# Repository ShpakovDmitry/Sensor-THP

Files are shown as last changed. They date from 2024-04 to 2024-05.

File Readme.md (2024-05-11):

<p align="right">
  
</p>

### Status
<p align="left">
  
  
  </br>
  
  
</p>

### Description
Wireless 2.4GHz temperature, humidity and atmospheric pressure sensor.

### Rendered board view

<p align="middle">
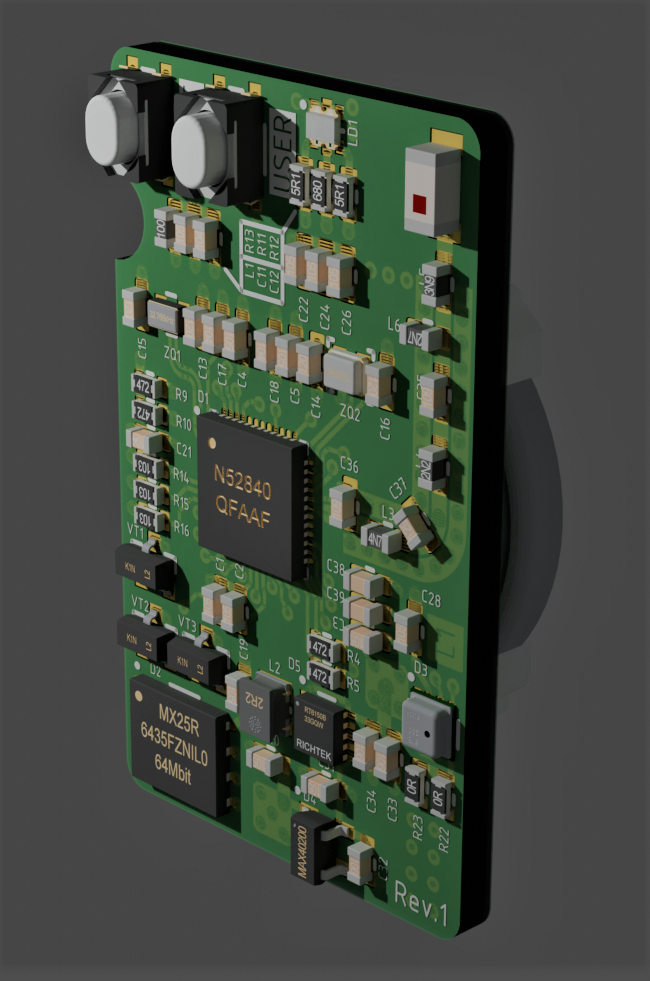
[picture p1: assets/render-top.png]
  
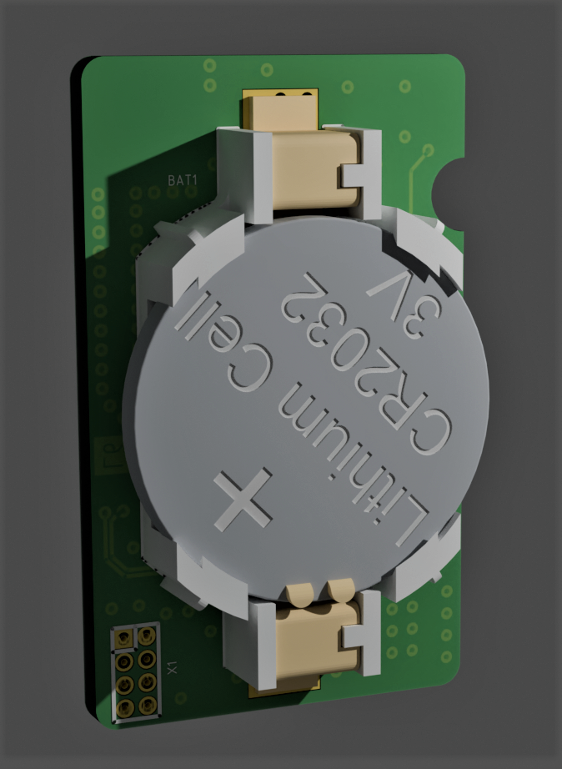
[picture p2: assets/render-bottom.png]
   
</p>

### Hardware
For hardware related information, like where is programming interface and its
pinout, board layout, fabrication files, documentation and schematics, goto
hardware directory.

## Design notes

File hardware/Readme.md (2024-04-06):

### Board view
With components 
<p align="middle">
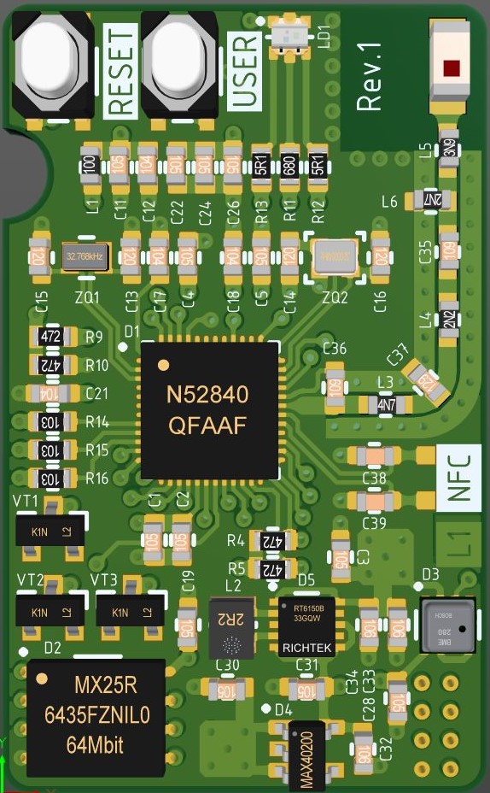
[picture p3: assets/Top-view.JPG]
  
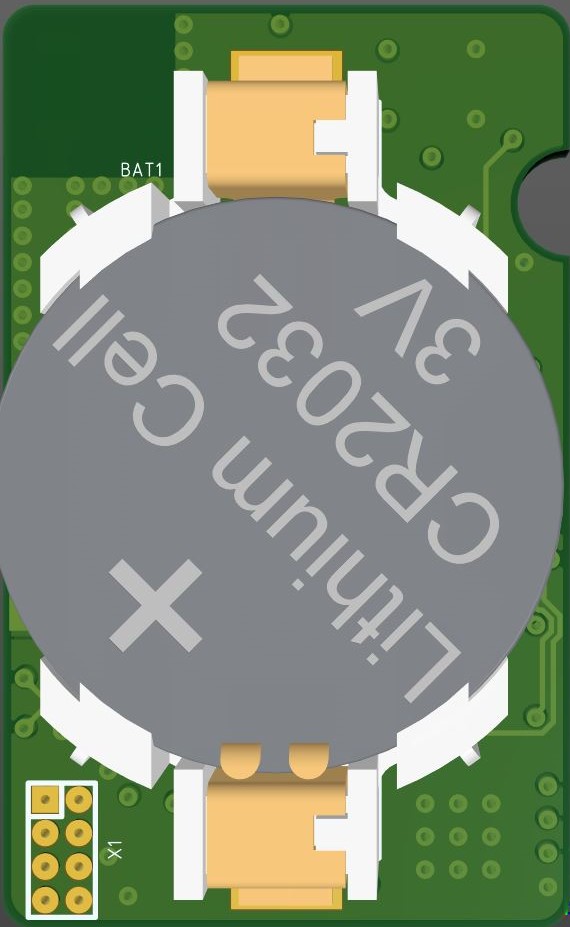
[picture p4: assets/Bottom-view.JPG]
  
</p> 
Without components
<p align="middle">
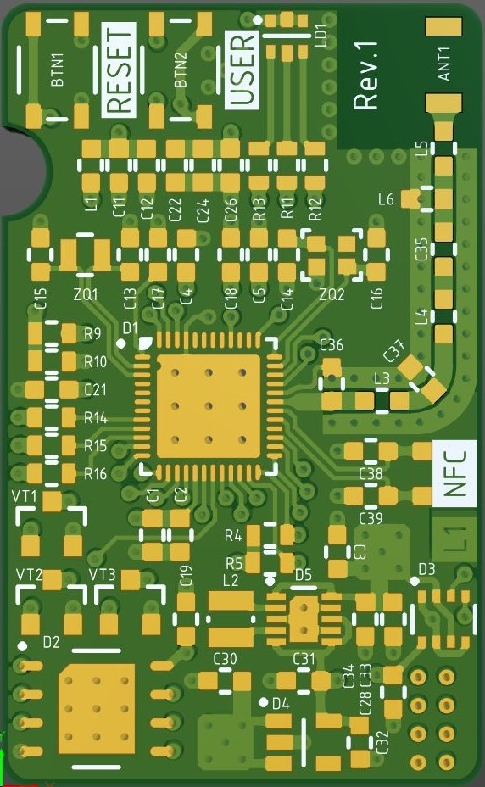
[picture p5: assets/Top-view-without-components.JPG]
  
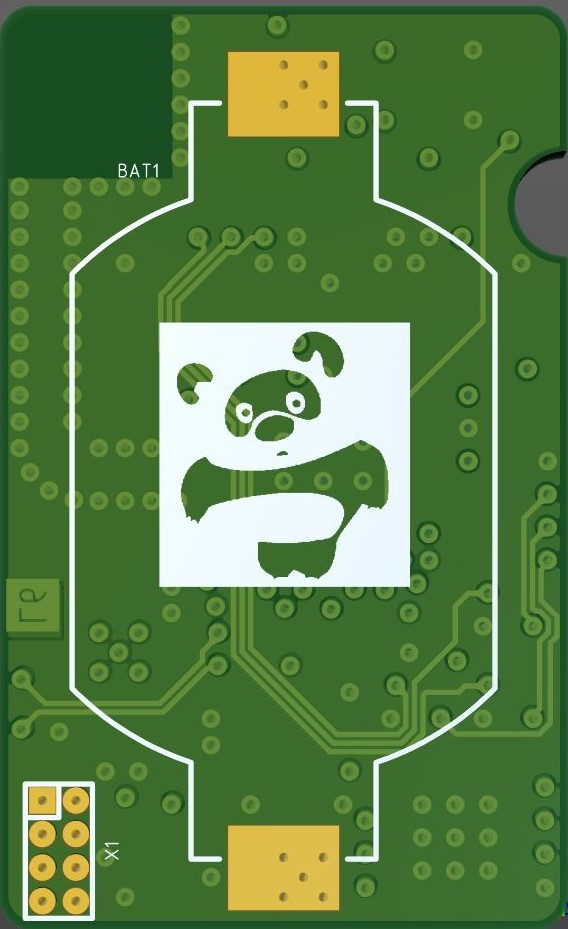
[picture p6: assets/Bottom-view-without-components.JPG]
  
</p> 

### Programming interface
<p align="middle">
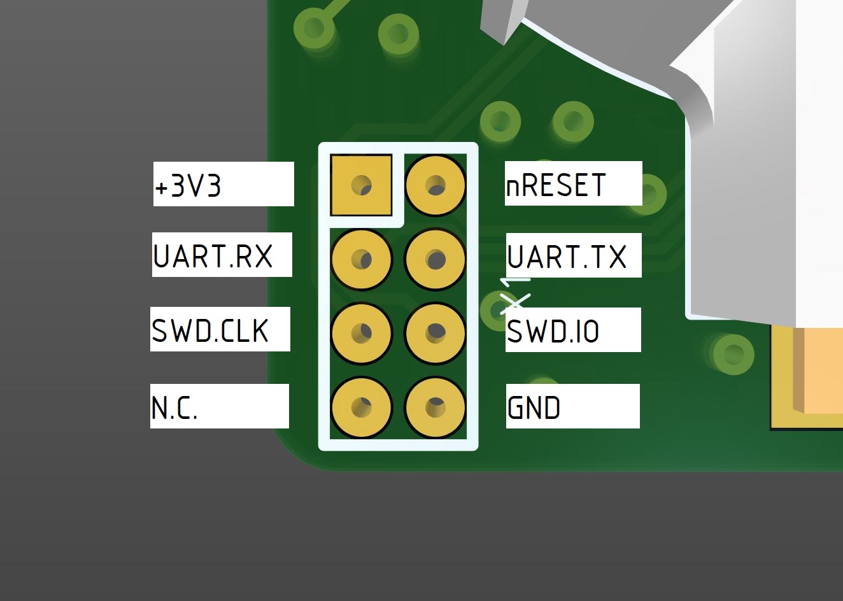
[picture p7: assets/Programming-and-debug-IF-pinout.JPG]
  
</p>

### Layer stackup
Board is 6 layer stackup with the following layer purpose:
<p align="middle">
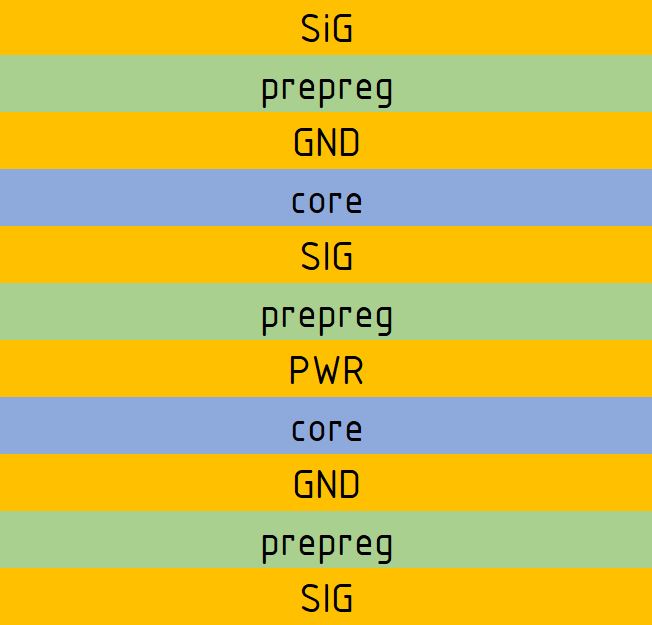
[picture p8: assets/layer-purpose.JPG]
  
</p> 

Detailed information about PCB layer stackup could be find
here

### Layer view
<p align="middle">
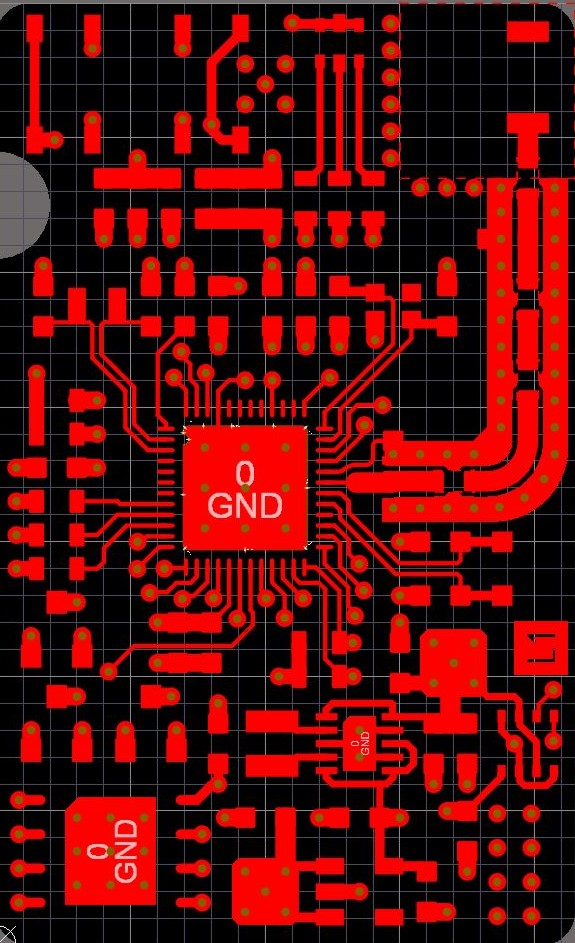
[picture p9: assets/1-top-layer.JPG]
  
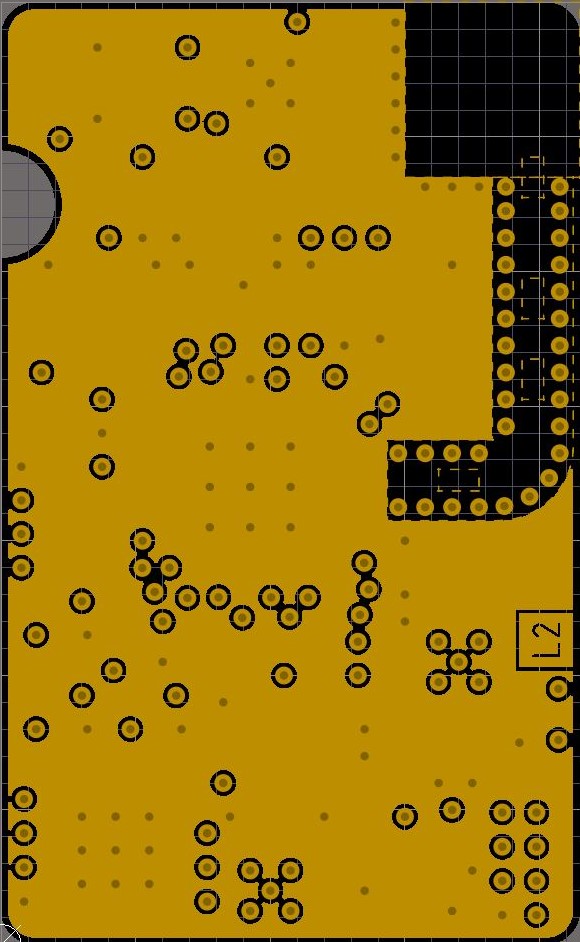
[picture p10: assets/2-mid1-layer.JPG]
  
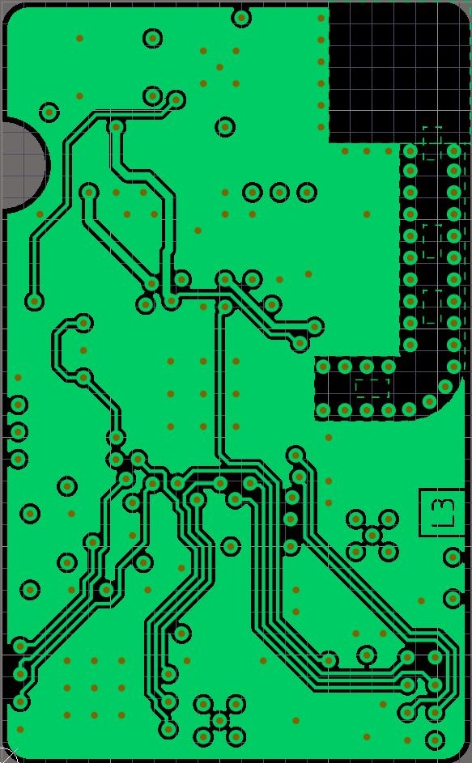
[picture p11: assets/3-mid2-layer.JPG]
  
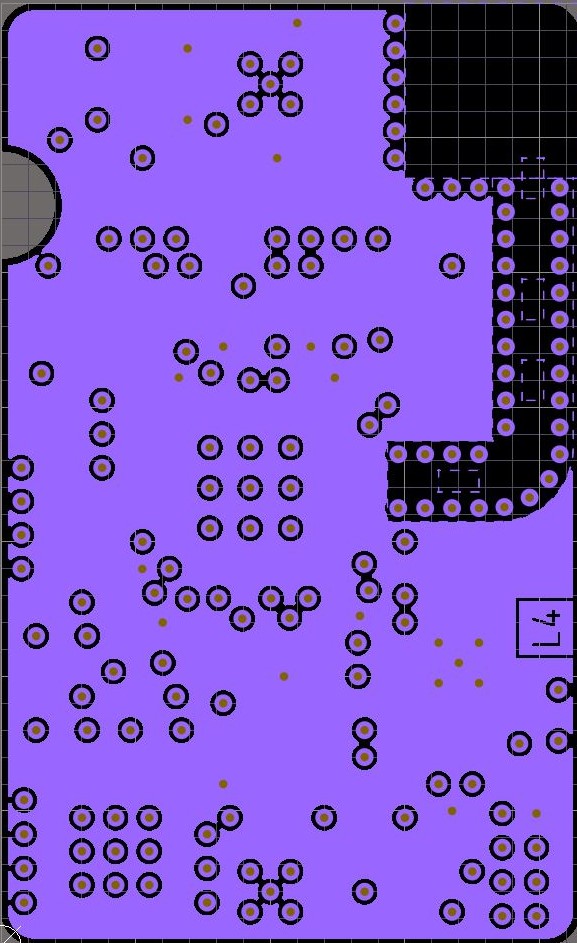
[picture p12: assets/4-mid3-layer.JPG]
  
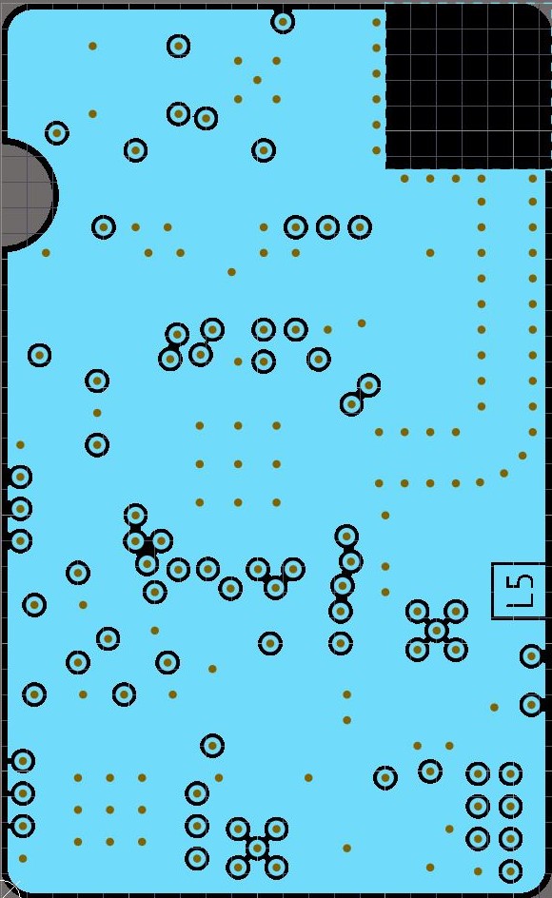
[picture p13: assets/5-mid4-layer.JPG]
  
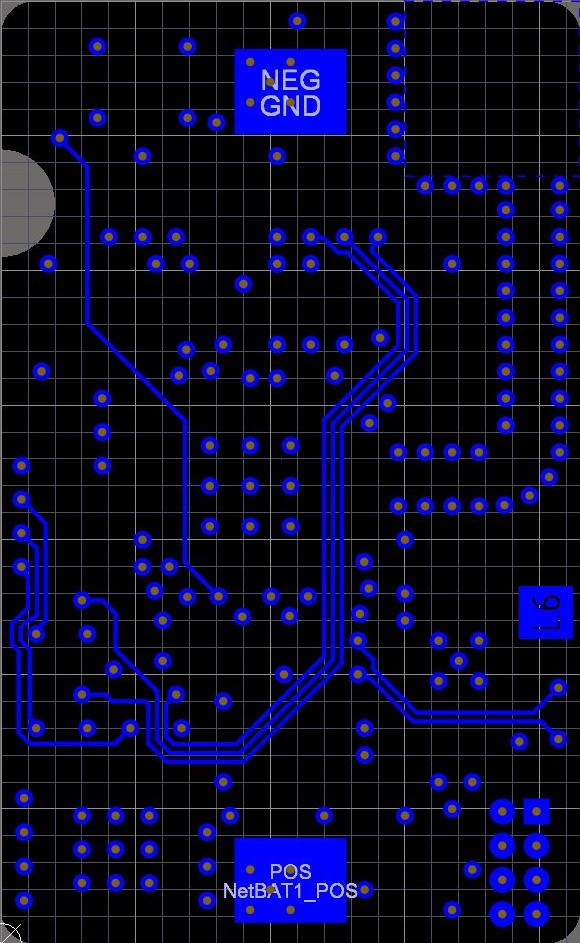
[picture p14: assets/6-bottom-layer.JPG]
  
</p>

### Schematics
Up to date version of schematics is here

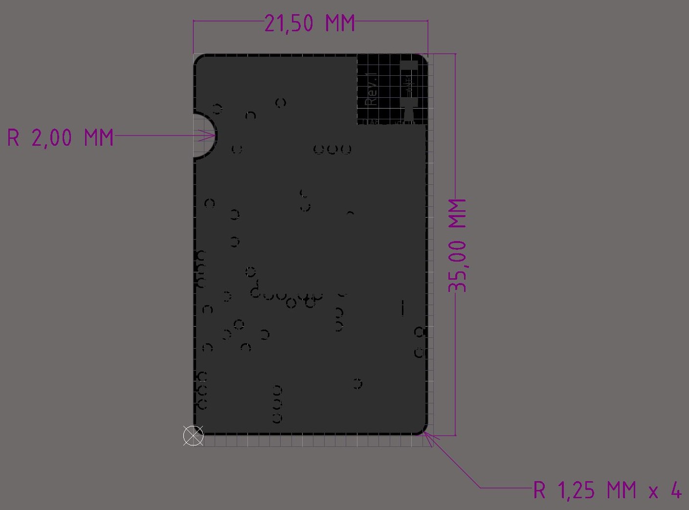
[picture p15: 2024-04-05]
assets/board-dimensions.JPG

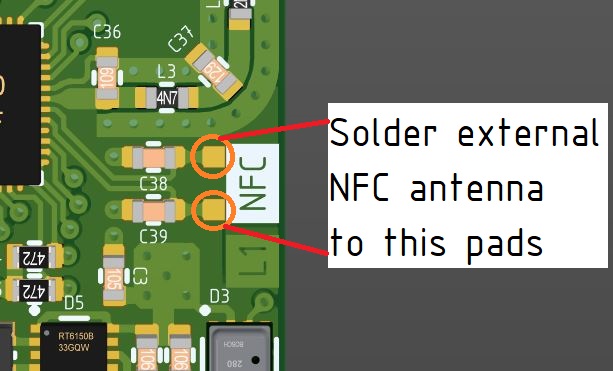
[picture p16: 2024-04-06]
assets/NFC-antenna-connection-IF.JPG

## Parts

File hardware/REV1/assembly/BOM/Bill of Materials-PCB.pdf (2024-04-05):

Designator | Quantity Assembly | | Package | Comment | Description | Manufacturer | Manufacturer Part Number | HelpURL | | | Supplier | Supplier Part Number | Price @ 1 pcsPrice @ 10 pcsPrice @ 100 pcsPrice @ 1000 pcs Last Update | | | | | Total cost for 1 PCB | Total cost for 10 PCB | Total cost for 100 PCB | Total cost for 1000 PCB
ANT1 | 1 | | | 2450AT18A0100001E | 2.4GHz Chip RF Antenna 2.4GHz ~ 2.5GHz 0.5dBi Solder Surface Mount | Johanson Technology Inc. | 2450AT18A0100001E | | -40°C | +125°C | DigiKey | 712-2450AT18A0100001ECT-ND | 0.55000€ | 0.48500€ | 0.37170€ | 0.23502€ | 2024.03.06 | 0.55 € | 4.85 € | 37.17 € | 235.02 €
BAT1 | 1 | | | BU2032SM-BT-GTR | Battery Holder (Open) Coin, 20.0mm 1 Cell SMD (SMT) Tab | MPD (Memory Protection Devices) | BU2032SM-BT-GTR | | -40°C | +280°C | DigiKey | BU2032SM-BT-GCT-ND | 1.57000€ | 1.32300€ | 1.09600€ | 0.94604€ | 2024.02.15 | 1.57 € | 13.23 € | 109.60 € | 946.04 €
BTN1, BTN2 | 2 | | | PTS810 SJK 250 SMTR LFS | Tactile Switch SPST-NO Top Actuated Surface Mount | C&K | PTS810 SJK 250 SMTR LFS | | -40°C | +85°C | DigiKey | CKN10503CT-ND | 0.31000€ | 0.29700€ | 0.24280€ | 0.18445€ | 2024.02.09 | 0.62 € | 5.94 € | 48.56 € | 368.90 €
C1, C2, C3, C4, C5, C11, C19, C22, C24, C26, C28, C30, C31 | 13 | | 0603 | 1u | 1 µF ±10% 6.3V Ceramic Capacitor X5R 0603 (1608 Metric) | YAGEO | CC0603KRX5R5BB105 | | -55°C | +85°C | DigiKey | 311-1447-1-ND | 0.09000€ | 0.06100€ | 0.02890€ | 0.01765€ | 2024.02.06 | 0.79 € | 3.76 € | 22.95 € | 229.45 €
C12, C17, C18, C21 | 4 | | 0603 | 0.1u | 0.1 µF ±10% 10V Ceramic Capacitor X7R 0603 (1608 Metric) | YAGEO | CC0603KRX7R6BB104 | | -55°C | +125°C | DigiKey | 311-4055-1-ND | 0.09000€ | 0.06100€ | 0.02870€ | 0.01753€ | 2024.02.07 | 0.36 € | 2.44 € | 11.48 € | 70.12 €
C13, C14, C15, C16 | 4 | | 0603 | 12p | 12 pF ±5% 50V Ceramic Capacitor C0G, NP0 0603 (1608 Metric) | YAGEO | CC0603JPNPO9BN120 | | -55°C | +125°C | DigiKey | 13-CC0603JPNPO9BN120CT-ND | 0.09000€ | 0.04500€ | 0.01980€ | 0.01170€ | 2024.02.07 | 0.36 € | 1.80 € | 7.92 € | 46.80 €
C32, C33, C34 | 3 | | 0603 | 10u | 10 µF ±20% 6.3V Ceramic Capacitor X5R 0603 (1608 Metric) | YAGEO | CC0603MRX5R5BB106 | | -55°C | +85°C | DigiKey | 311-1448-1-ND | 0.20000€ | 0.13500€ | 0.07660€ | 0.04981€ | 2024.02.27 | 0.60 € | 4.05 € | 22.98 € | 149.43 €
C35, C36 | 2 | | 0603 | 1.0p | 1 pF ±0.1pF 250V Ceramic Capacitor C0G, NP0 0603 (1608 Metric) | Johanson Technology Inc. | QSCP251Q1R0B1GV001T | | -55°C | +125°C | DigiKey | 712-QSCP251Q1R0B1GV001TCT-ND | 0.20000€ | 0.13500€ | 0.07590€ | 0.04936€ | 2024.03.06 | 0.40 € | 2.70 € | 15.18 € | 98.72 €
C37 | 1 | | 0603 | 1.2p | 1.2 pF ±0.1pF 250V Ceramic Capacitor C0G, NP0 0603 (1608 Metric) | Johanson Technology Inc. | QSCP251Q1R2B1GV001T | | -55°C | +125°C | DigiKey | 712-QSCP251Q1R2B1GV001TCT-ND | 0.20000€ | 0.13400€ | 0.07590€ | 0.04936€ | 2024.03.06 | 0.20 € | 1.34 € | 7.59 € | 49.36 €
C38, C39 | 2 | DNP | 0603 | | | | | | | | | | | | | | | 0.00 € | 0.00 € | 0.00 € | 0.00 €
D1 | 1 | | QFN48 6x6mm 0.4mm pitch | nRF52840-QFAA-F | SoC 32bit ARM Cortex-M4F 1M Flash 256K RAM Single Core 64MHz 1.7V to 5.5V 2.4GHz Bluetooth 5.0 Surface Mount 48-Pin QFN | Nordic Semiconductor ASA | nRF52840-QFAA-F | | -40°C | +85°C | DigiKey | 4823-NRF52840-QFAA-F-RCT-ND | 5.98000€ | 5.48300€ | 4.48650€ | 3.36485€ | 2024.02.05 | 5.98 € | 54.83 € | 448.65 € | 3 364.85 €
D2 | 1 | | 8-WSON (6x5) 1.27mm pitch | MX25R6435FZNIL0 64MiB | FLASH - NOR Memory IC 64Mbit SPI - Quad I/O 80 MHz 8-WSON (6x5) | Macronix | MX25R6435FZNIL0 | | -40°C | +85°C | DigiKey | 1092-1201-ND | 1.72000€ | 1.56700€ | 1.35513€ | 1.33081€ | 2024.02.08 | 1.72 € | 15.67 € | 135.51 € | 1 330.81 €
D3 | 1 | | 8-LGA (2.5x2.5) | BME280 | Humidity, Pressure, Temperature 0 ~ 100% RH I2C, SPI ±3% 1 s Surface Mount | Bosch Sensortec | BME280 | | -40°C | +85°C | DigiKey | 828-1063-1-ND | 5.87000€ | 4.40400€ | 3.62050€ | 2.83773€ | 2024.02.13 | 5.87 € | 44.04 € | 362.05 € | 2 837.73 €
D4 | 1 | | SOT23-5 | MAX40200AUK+T | OR Controller Source Selector Switch P-Channel 1:1 SOT-23-5 | Analog Devices Inc./Maxim Integrated | MAX40200AUK+T | | -40°C | +125°C | DigiKey | MAX40200AUK+TCT-ND | 0.93000€ | 0.76500€ | 0.59560€ | 0.41122€ | 2024.02.27 | 0.93 € | 7.65 € | 59.56 € | 411.22 €
D5 | 1 | | 10-WDFN (2.5x2.5) | RT6150B-33GQW | Buck-Boost Switching Regulator IC Positive Fixed 3.3V 1 Output 800mA 10-WFDFN Exposed Pad | Richtek USA Inc. | RT6150B-33GQW | | -40°C | +85°C | DigiKey | RT6150B-33GQWCT-ND | 1.80000€ | 1.61400€ | 1.29720€ | 1.06576€ | 2024.02.27 | 1.80 € | 16.14 € | 129.72 € | 1 065.76 €
L1 | 1 | | 0603 | 10uH | 10 µH Shielded Multilayer Inductor 250 mA 1.05Ohm 0603 (1608 Metric) | TDK Corporation | MLZ1608M100WTD25 | | -55°C | +125°C | DigiKey | 445-175588-1-ND | 0.16000€ | 0.13600€ | 0.09630€ | 0.06609€ | 2024.02.08 | 0.16 € | 1.36 € | 9.63 € | 66.09 €
L2 | 1 | | 2520 | 2.2uH | 2.2 µH Shielded Drum Core, Wirewound Inductor 1.87 A 96mOhm Max Nonstandard | TDK Corporation | VLS252012CX-2R2M-1 | | -40°C | +105°C | DigiKey | 445-172983-1-ND | 0.35000€ | 0.29900€ | 0.22220€ | 0.15979€ | 2024.02.27 | 0.35 € | 2.99 € | 22.22 € | 159.79 €
L3 | 1 | | 0603 | 4.7nH | 4.7 nH Unshielded Multilayer Inductor 300 mA 300mOhm Max 0603 (1608 Metric) | Johanson Technology Inc. | LRC0603CS4N7GV001T | | -55°C | +100°C | DigiKey | 712-LRC0603CS4N7GV001TCT-ND | 0.09000€ | 0.04300€ | 0.03060€ | 0.02098€ | 2024.03.07 | 0.09 € | 0.43 € | 3.06 € | 20.98 €
L4 | 1 | | 0603 | 2.2nH | 2.2 nH Unshielded Multilayer Inductor 300 mA 150mOhm Max 0603 (1608 Metric) | Johanson Technology Inc. | LRC0603CS2N2GV001T | | -55°C | +100°C | DigiKey | 712-LRC0603CS2N2GV001TCT-ND | 0.09000€ | 0.04300€ | 0.03060€ | 0.02098€ | 2024.03.07 | 0.09 € | 0.43 € | 3.06 € | 20.98 €
L5 | 1 | | 0603 | 3.9nH | 3.9 nH Unshielded Multilayer Inductor 300 mA 250mOhm Max 0603 (1608 Metric) | Johanson Technology Inc. | LRC0603CS3N9GV001T | | -55°C | +100°C | DigiKey | 712-LRC0603CS3N9GV001TCT-ND | 0.09000€ | 0.04300€ | 0.03060€ | 0.02098€ | 2024.03.07 | 0.09 € | 0.43 € | 3.06 € | 20.98 €
L6 | 1 | | 0603 | 2.7nH | 2.7 nH Unshielded Multilayer Inductor 300 mA 200mOhm Max 0603 (1608 Metric) | Johanson Technology Inc. | LRC0603CS2N7GV001T | | -55°C | +100°C | DigiKey | 712-LRC0603CS2N7GV001TCT-ND | 0.09000€ | 0.04300€ | 0.03060€ | 0.02098€ | 2024.03.07 | 0.09 € | 0.43 € | 3.06 € | 20.98 €
LD1 | 1 | | 0606 | EAST1616RGBA8 | Red, Green, Blue (RGB) 624nm Red, 525nm Green, 468nm Blue LED Indication - Discrete 2.05V Red, 3.2V Green, 3.2V Blue 0606 (1616 Metric) | Everlight Electronics Co Ltd | EAST1616RGBA8 | | -40°C | +85°C | DigiKey | 1080-EAST1616RGBA8CT-ND | 0.48000€ | 0.29500€ | 0.16980€ | 0.13293€ | 2024.02.14 | 0.48 € | 2.95 € | 16.98 € | 132.93 €
R4, R5, R9, R10 | 4 | | 0603 | 4k7 | 4.7 kOhms ±5% 0.1W, 1/10W Chip Resistor 0603 (1608 Metric) Moisture Resistant Thick Film | YAGEO | RC0603JR-074K7L | | -55°C | +155°C | DigiKey | 311-4.7KGRCT-ND | 0.09000€ | 0.01400€ | 0.00690€ | 0.00399€ | 2024.02.09 | 0.36 € | 0.56 € | 2.76 € | 15.96 €
R11 | 1 | | 0603 | 68R | 68 Ohms ±1% 0.1W, 1/10W Chip Resistor 0603 (1608 Metric) Moisture Resistant Thick Film | YAGEO | RC0603FR-0768RL | | -55°C | +155°C | DigiKey | 311-68.0HRCT-ND | 0.09000€ | 0.01700€ | 0.00850€ | 0.00486€ | 2024.02.14 | 0.09 € | 0.17 € | 0.85 € | 4.86 €
R12, R13 | 2 | | 0603 | 5R1 | 5.1 Ohms ±5% 0.1W, 1/10W Chip Resistor 0603 (1608 Metric) Moisture Resistant Thick Film | YAGEO | RC0603JR-075R1L | | -55°C | +155°C | DigiKey | 311-5.1GRCT-ND | 0.09000€ | 0.02400€ | 0.01250€ | 0.00743€ | 2024.02.14 | 0.18 € | 0.48 € | 2.50 € | 14.86 €
R14, R15, R16 | 3 | | 0603 | 10k | 10 kOhms ±1% 0.1W, 1/10W Chip Resistor 0603 (1608 Metric) Moisture Resistant Thick Film | YAGEO | RC0603FR-0710KL | | -55°C | +155°C | DigiKey | 311-10.0KHRCT-ND | 0.09000€ | 0.01700€ | 0.00850€ | 0.00486€ | 2024.02.14 | 0.27 € | 0.51 € | 2.55 € | 14.58 €
VT1, VT2, VT3 | 3 | | SOT-23-3 | MMBT3904-7-F | Bipolar (BJT) Transistor NPN 40 V 200 mA 300MHz 300 mW Surface Mount SOT-23-3 | Diodes Incorporated | MMBT3904-7-F | | -55°C | +150°C | DigiKey | MMBT3904-FDICT-ND | 0.11000€ | 0.07900€ | 0.04270€ | 0.02326€ | 2024.02.14 | 0.33 € | 2.37 € | 12.81 € | 69.78 €
ZQ1 | 1 | | 2-smd | 32.768kHz | 32.768 kHz ±20ppm Crystal 9pF 90 kOhms 2-SMD, No Lead | Jauch Quartz Q 0,032768-JTX210-9-20-T1-80K-LF | | | -40°C | +85°C | DigiKey | 1908-1304-1-ND | 0.60000€ | 0.53100€ | 0.43850€ | 0.34618€ | 2024.02.08 | 0.60 € | 5.31 € | 43.85 € | 346.18 €
ZQ2 | 1 | | 4-smd | 32.0000MHz | 32 MHz ±20ppm Crystal 8pF 100 Ohms 4-SMD, No Lead | Murata Electronics | XRCGB32M000F2P01R0 | | -30°C | +85°C | DigiKey | 490-18340-1-ND | 0.20000€ | 0.16700€ | 0.13390€ | 0.11791€ | 2024.02.07 | 0.20 € | 1.67 € | 13.39 € | 117.91 €
Total: | 25.13 € | 198.53 € | 1 558.70 € | 12 231.07 €

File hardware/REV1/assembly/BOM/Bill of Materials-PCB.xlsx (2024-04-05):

Designator | Quantity | Assembly | Package | Comment | Description | Manufacturer | Manufacturer Part Number | HelpURL | Min Operating Temperature | Max Operating Temperature | Supplier | Supplier Part Number | Price @ 1 pcs | Price @ 10 pcs | Price @ 100 pcs | Price @ 1000 pcs | Last Update |  | Total cost for 1 PCB | Total cost for 10 PCB | Total cost for 100 PCB | Total cost for 1000 PCB
ANT1 | 1 |  |  | 2450AT18A0100001E | 2.4GHz Chip RF Antenna 2.4GHz ~ 2.5GHz 0.5dBi Solder Surface Mount | Johanson Technology Inc. | 2450AT18A0100001E | https://www.digikey.com/en/products/detail/johanson-technology-inc/2450AT18A0100001E/1560676 | -40°C | +125°C | DigiKey | 712-2450AT18A0100001ECT-ND | 0.55000€ | 0.48500€ | 0.37170€ | 0.23502€ | 2024.03.06 |  | 0.55 € | 4.85 € | 37.17 € | 235.02 €
BAT1 | 1 |  |  | BU2032SM-BT-GTR | Battery Holder (Open) Coin, 20.0mm 1 Cell SMD (SMT) Tab | MPD (Memory Protection Devices) | BU2032SM-BT-GTR | https://www.digikey.com/en/products/detail/mpd-memory-protection-devices/BU2032SM-BT-GTR/2439521 | -40°C | +280°C | DigiKey | BU2032SM-BT-GCT-ND | 1.57000€ | 1.32300€ | 1.09600€ | 0.94604€ | 2024.02.15 |  | 1.57 € | 13.23 € | 109.60 € | 946.04 €
BTN1, BTN2 | 2 |  |  | PTS810 SJK 250 SMTR LFS | Tactile Switch SPST-NO Top Actuated Surface Mount | C&K | PTS810 SJK 250 SMTR LFS | https://www.digikey.com/en/products/detail/c-k/PTS810-SJK-250-SMTR-LFS/4176611 | -40°C | +85°C | DigiKey | CKN10503CT-ND | 0.31000€ | 0.29700€ | 0.24280€ | 0.18445€ | 2024.02.09 |  | 0.62 € | 5.94 € | 48.56 € | 368.90 €
C1, C2, C3, C4, C5, C11, C19, C22, C24, C26, C28, C30, C31 | 13 |  | 0603 | 1u | 1 µF ±10% 6.3V Ceramic Capacitor X5R 0603 (1608 Metric) | YAGEO | CC0603KRX5R5BB105 | https://www.digikey.com/en/products/detail/yageo/CC0603KRX5R5BB105/2833612 | -55°C | +85°C | DigiKey | 311-1447-1-ND | 0.09000€ | 0.06100€ | 0.02890€ | 0.01765€ | 2024.02.06 |  | 0.79 € | 3.76 € | 22.95 € | 229.45 €
C12, C17, C18, C21 | 4 |  | 0603 | 0.1u | 0.1 µF ±10% 10V Ceramic Capacitor X7R 0603 (1608 Metric) | YAGEO | CC0603KRX7R6BB104 | https://www.digikey.com/en/products/detail/yageo/CC0603KRX7R6BB104/5883741 | -55°C | +125°C | DigiKey | 311-4055-1-ND | 0.09000€ | 0.06100€ | 0.02870€ | 0.01753€ | 2024.02.07 |  | 0.36 € | 2.44 € | 11.48 € | 70.12 €
C13, C14, C15, C16 | 4 |  | 0603 | 12p | 12 pF ±5% 50V Ceramic Capacitor C0G, NP0 0603 (1608 Metric) | YAGEO | CC0603JPNPO9BN120 | https://www.digikey.com/en/products/detail/yageo/CC0603JPNPO9BN120/11490158 | -55°C | +125°C | DigiKey | 13-CC0603JPNPO9BN120CT-ND | 0.09000€ | 0.04500€ | 0.01980€ | 0.01170€ | 2024.02.07 |  | 0.36 € | 1.80 € | 7.92 € | 46.80 €
C32, C33, C34 | 3 |  | 0603 | 10u | 10 µF ±20% 6.3V Ceramic Capacitor X5R 0603 (1608 Metric) | YAGEO | CC0603MRX5R5BB106 | https://www.digikey.com/en/products/detail/yageo/CC0603MRX5R5BB106/2833613 | -55°C | +85°C | DigiKey | 311-1448-1-ND | 0.20000€ | 0.13500€ | 0.07660€ | 0.04981€ | 2024.02.27 |  | 0.60 € | 4.05 € | 22.98 € | 149.43 €
C35, C36 | 2 |  | 0603 | 1.0p | 1 pF ±0.1pF 250V Ceramic Capacitor C0G, NP0 0603 (1608 Metric) | Johanson Technology Inc. | QSCP251Q1R0B1GV001T | https://www.digikey.com/en/products/detail/johanson-technology-inc/QSCP251Q1R0B1GV001T/1561575 | -55°C | +125°C | DigiKey | 712-QSCP251Q1R0B1GV001TCT-ND | 0.20000€ | 0.13500€ | 0.07590€ | 0.04936€ | 2024.03.06 |  | 0.40 € | 2.70 € | 15.18 € | 98.72 €
C37 | 1 |  | 0603 | 1.2p | 1.2 pF ±0.1pF 250V Ceramic Capacitor C0G, NP0 0603 (1608 Metric) | Johanson Technology Inc. | QSCP251Q1R2B1GV001T | https://www.digikey.com/en/products/detail/johanson-technology-inc/QSCP251Q1R2B1GV001T/1561577 | -55°C | +125°C | DigiKey | 712-QSCP251Q1R2B1GV001TCT-ND | 0.20000€ | 0.13400€ | 0.07590€ | 0.04936€ | 2024.03.06 |  | 0.20 € | 1.34 € | 7.59 € | 49.36 €
C38, C39 | 2 | DNP | 0603 |  |  |  |  |  |  |  |  |  |  |  |  |  |  |  | 0.00 € | 0.00 € | 0.00 € | 0.00 €
D1 | 1 |  | QFN48 6x6mm 0.4mm pitch | nRF52840-QFAA-F | SoC 32bit ARM Cortex-M4F 1M Flash 256K RAM Single Core 64MHz 1.7V to 5.5V 2.4GHz Bluetooth 5.0 Surface Mount 48-Pin QFN | Nordic Semiconductor ASA | nRF52840-QFAA-F | https://infocenter.nordicsemi.com/pdf/nRF52840_PS_v1.7.pdf | -40°C | +85°C | DigiKey | 4823-NRF52840-QFAA-F-RCT-ND | 5.98000€ | 5.48300€ | 4.48650€ | 3.36485€ | 2024.02.05 |  | 5.98 € | 54.83 € | 448.65 € | 3364.85 €
D2 | 1 |  | 8-WSON (6x5) 1.27mm pitch | MX25R6435FZNIL0 64MiB | FLASH - NOR Memory IC 64Mbit SPI - Quad I/O 80 MHz 8-WSON (6x5) | Macronix | MX25R6435FZNIL0 | https://www.digikey.com/en/products/detail/macronix/MX25R6435FZNIL0/6558605 | -40°C | +85°C | DigiKey | 1092-1201-ND | 1.72000€ | 1.56700€ | 1.35513€ | 1.33081€ | 2024.02.08 |  | 1.72 € | 15.67 € | 135.51 € | 1330.81 €
D3 | 1 |  | 8-LGA (2.5x2.5) | BME280 | Humidity, Pressure, Temperature 0 ~ 100% RH I2C, SPI ±3% 1 s Surface Mount | Bosch Sensortec | BME280 | https://www.digikey.com/en/products/detail/bosch-sensortec/BME280/6136306 | -40°C | +85°C | DigiKey | 828-1063-1-ND | 5.87000€ | 4.40400€ | 3.62050€ | 2.83773€ | 2024.02.13 |  | 5.87 € | 44.04 € | 362.05 € | 2837.73 €
D4 | 1 |  | SOT23-5 | MAX40200AUK+T | OR Controller Source Selector Switch P-Channel 1:1 SOT-23-5 | Analog Devices Inc./Maxim Integrated | MAX40200AUK+T | https://www.digikey.com/en/products/detail/analog-devices-inc-maxim-integrated/MAX40200AUK-T/7392218 | -40°C | +125°C | DigiKey | MAX40200AUK+TCT-ND | 0.93000€ | 0.76500€ | 0.59560€ | 0.41122€ | 2024.02.27 |  | 0.93 € | 7.65 € | 59.56 € | 411.22 €
D5 | 1 |  | 10-WDFN (2.5x2.5) | RT6150B-33GQW | Buck-Boost Switching Regulator IC Positive Fixed 3.3V 1 Output 800mA 10-WFDFN Exposed Pad | Richtek USA Inc. | RT6150B-33GQW | https://www.digikey.com/en/products/detail/richtek-usa-inc/RT6150B-33GQW/6676709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 | -40°C | +85°C | DigiKey | RT6150B-33GQWCT-ND | 1.80000€ | 1.61400€ | 1.29720€ | 1.06576€ | 2024.02.27 |  | 1.80 € | 16.14 € | 129.72 € | 1065.76 €
L1 | 1 |  | 0603 | 10uH | 10 µH Shielded Multilayer Inductor 250 mA 1.05Ohm 0603 (1608 Metric) | TDK Corporation | MLZ1608M100WTD25 | https://www.digikey.com/en/products/detail/tdk-corporation/MLZ1608M100WTD25/4743176 | -55°C | +125°C | DigiKey | 445-175588-1-ND | 0.16000€ | 0.13600€ | 0.09630€ | 0.06609€ | 2024.02.08 |  | 0.16 € | 1.36 € | 9.63 € | 66.09 €
L2 | 1 |  | 2520 | 2.2uH | 2.2 µH Shielded Drum Core, Wirewound Inductor 1.87 A 96mOhm Max Nonstandard | TDK Corporation | VLS252012CX-2R2M-1 | https://www.digikey.com/en/products/detail/tdk-corporation/VLS252012CX-2R2M-1/5169788 | -40°C | +105°C | DigiKey | 445-172983-1-ND | 0.35000€ | 0.29900€ | 0.22220€ | 0.15979€ | 2024.02.27 |  | 0.35 € | 2.99 € | 22.22 € | 159.79 €
L3 | 1 |  | 0603 | 4.7nH | 4.7 nH Unshielded Multilayer Inductor 300 mA 300mOhm Max 0603 (1608 Metric) | Johanson Technology Inc. | LRC0603CS4N7GV001T | https://www.digikey.com/en/products/detail/johanson-technology-inc/LRC0603CS4N7GV001T/1561296 | -55°C | +100°C | DigiKey | 712-LRC0603CS4N7GV001TCT-ND | 0.09000€ | 0.04300€ | 0.03060€ | 0.02098€ | 2024.03.07 |  | 0.09 € | 0.43 € | 3.06 € | 20.98 €
L4 | 1 |  | 0603 | 2.2nH | 2.2 nH Unshielded Multilayer Inductor 300 mA 150mOhm Max 0603 (1608 Metric) | Johanson Technology Inc. | LRC0603CS2N2GV001T | https://www.digikey.com/en/products/detail/johanson-technology-inc/LRC0603CS2N2GV001T/1561288 | -55°C | +100°C | DigiKey | 712-LRC0603CS2N2GV001TCT-ND | 0.09000€ | 0.04300€ | 0.03060€ | 0.02098€ | 2024.03.07 |  | 0.09 € | 0.43 € | 3.06 € | 20.98 €
L5 | 1 |  | 0603 | 3.9nH | 3.9 nH Unshielded Multilayer Inductor 300 mA 250mOhm Max 0603 (1608 Metric) | Johanson Technology Inc. | LRC0603CS3N9GV001T | https://www.digikey.com/en/products/detail/johanson-technology-inc/LRC0603CS3N9GV001T/1561294 | -55°C | +100°C | DigiKey | 712-LRC0603CS3N9GV001TCT-ND | 0.09000€ | 0.04300€ | 0.03060€ | 0.02098€ | 2024.03.07 |  | 0.09 € | 0.43 € | 3.06 € | 20.98 €
L6 | 1 |  | 0603 | 2.7nH | 2.7 nH Unshielded Multilayer Inductor 300 mA 200mOhm Max 0603 (1608 Metric) | Johanson Technology Inc. | LRC0603CS2N7GV001T | https://www.digikey.com/en/products/detail/johanson-technology-inc/LRC0603CS2N7GV001T/1561291 | -55°C | +100°C | DigiKey | 712-LRC0603CS2N7GV001TCT-ND | 0.09000€ | 0.04300€ | 0.03060€ | 0.02098€ | 2024.03.07 |  | 0.09 € | 0.43 € | 3.06 € | 20.98 €
LD1 | 1 |  | 0606 | EAST1616RGBA8 | Red, Green, Blue (RGB) 624nm Red, 525nm Green, 468nm Blue LED Indication - Discrete 2.05V Red, 3.2V Green, 3.2V Blue 0606 (1616 Metric) | Everlight Electronics Co Ltd | EAST1616RGBA8 | https://www.digikey.com/en/products/detail/everlight-electronics-co-ltd/EAST1616RGBA8/11560367 | -40°C | +85°C | DigiKey | 1080-EAST1616RGBA8CT-ND | 0.48000€ | 0.29500€ | 0.16980€ | 0.13293€ | 2024.02.14 |  | 0.48 € | 2.95 € | 16.98 € | 132.93 €
R4, R5, R9, R10 | 4 |  | 0603 | 4k7 | 4.7 kOhms ±5% 0.1W, 1/10W Chip Resistor 0603 (1608 Metric) Moisture Resistant Thick Film | YAGEO | RC0603JR-074K7L | https://www.digikey.com/en/products/detail/yageo/RC0603JR-074K7L/726785 | -55°C | +155°C | DigiKey | 311-4.7KGRCT-ND | 0.09000€ | 0.01400€ | 0.00690€ | 0.00399€ | 2024.02.09 |  | 0.36 € | 0.56 € | 2.76 € | 15.96 €
R11 | 1 |  | 0603 | 68R | 68 Ohms ±1% 0.1W, 1/10W Chip Resistor 0603 (1608 Metric) Moisture Resistant Thick Film | YAGEO | RC0603FR-0768RL | https://www.digikey.com/en/products/detail/yageo/RC0603FR-0768RL/727351 | -55°C | +155°C | DigiKey | 311-68.0HRCT-ND | 0.09000€ | 0.01700€ | 0.00850€ | 0.00486€ | 2024.02.14 |  | 0.09 € | 0.17 € | 0.85 € | 4.86 €
R12, R13 | 2 |  | 0603 | 5R1 | 5.1 Ohms ±5% 0.1W, 1/10W Chip Resistor 0603 (1608 Metric) Moisture Resistant Thick Film | YAGEO | RC0603JR-075R1L | https://www.digikey.com/en/products/detail/yageo/RC0603JR-075R1L/726795 | -55°C | +155°C | DigiKey | 311-5.1GRCT-ND | 0.09000€ | 0.02400€ | 0.01250€ | 0.00743€ | 2024.02.14 |  | 0.18 € | 0.48 € | 2.50 € | 14.86 €
R14, R15, R16 | 3 |  | 0603 | 10k | 10 kOhms ±1% 0.1W, 1/10W Chip Resistor 0603 (1608 Metric) Moisture Resistant Thick Film | YAGEO | RC0603FR-0710KL | https://www.digikey.com/en/products/detail/yageo/RC0603FR-0710KL/726880 | -55°C | +155°C | DigiKey | 311-10.0KHRCT-ND | 0.09000€ | 0.01700€ | 0.00850€ | 0.00486€ | 2024.02.14 |  | 0.27 € | 0.51 € | 2.55 € | 14.58 €
VT1, VT2, VT3 | 3 |  | SOT-23-3 | MMBT3904-7-F | Bipolar (BJT) Transistor NPN 40 V 200 mA 300MHz 300 mW Surface Mount SOT-23-3 | Diodes Incorporated | MMBT3904-7-F | https://www.digikey.com/en/products/detail/diodes-incorporated/MMBT3904-7-F/814494 | -55°C | +150°C | DigiKey | MMBT3904-FDICT-ND | 0.11000€ | 0.07900€ | 0.04270€ | 0.02326€ | 2024.02.14 |  | 0.33 € | 2.37 € | 12.81 € | 69.78 €
ZQ1 | 1 |  | 2-smd | 32.768kHz | 32.768 kHz ±20ppm Crystal 9pF 90 kOhms 2-SMD, No Lead | Jauch Quartz | Q 0,032768-JTX210-9-20-T1-80K-LF | https://www.digikey.com/en/products/detail/jauch-quartz/Q-0-032768-JTX210-9-20-T1-80K-LF/8108074 | -40°C | +85°C | DigiKey | 1908-1304-1-ND | 0.60000€ | 0.53100€ | 0.43850€ | 0.34618€ | 2024.02.08 |  | 0.60 € | 5.31 € | 43.85 € | 346.18 €
ZQ2 | 1 |  | 4-smd | 32.0000MHz | 32 MHz ±20ppm Crystal 8pF 100 Ohms 4-SMD, No Lead | Murata Electronics | XRCGB32M000F2P01R0 | https://www.digikey.com/en/products/detail/murata-electronics/XRCGB32M000F2P01R0/9959697 | -30°C | +85°C | DigiKey | 490-18340-1-ND | 0.20000€ | 0.16700€ | 0.13390€ | 0.11791€ | 2024.02.07 |  | 0.20 € | 1.67 € | 13.39 € | 117.91 €
 |  |  |  |  |  |  |  |  |  |  |  |  |  |  |  |  |  | Total: | 25.13 € | 198.53 € | 1558.70 € | 12231.07 €

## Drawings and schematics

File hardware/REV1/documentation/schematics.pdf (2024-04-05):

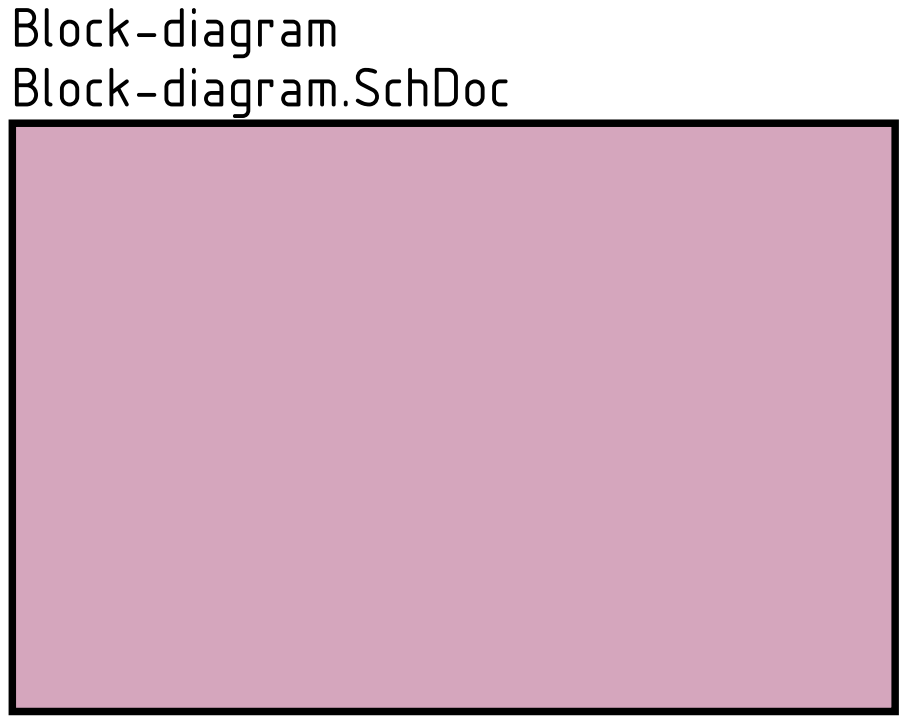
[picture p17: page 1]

Author | DmitryShpakov | Title | Title-page.SchDoc

Date | 04.04.2024

Organization | NoName

Page | 1

Total pages | | BLE sensor | Rev.1

Page size | A4

Materials

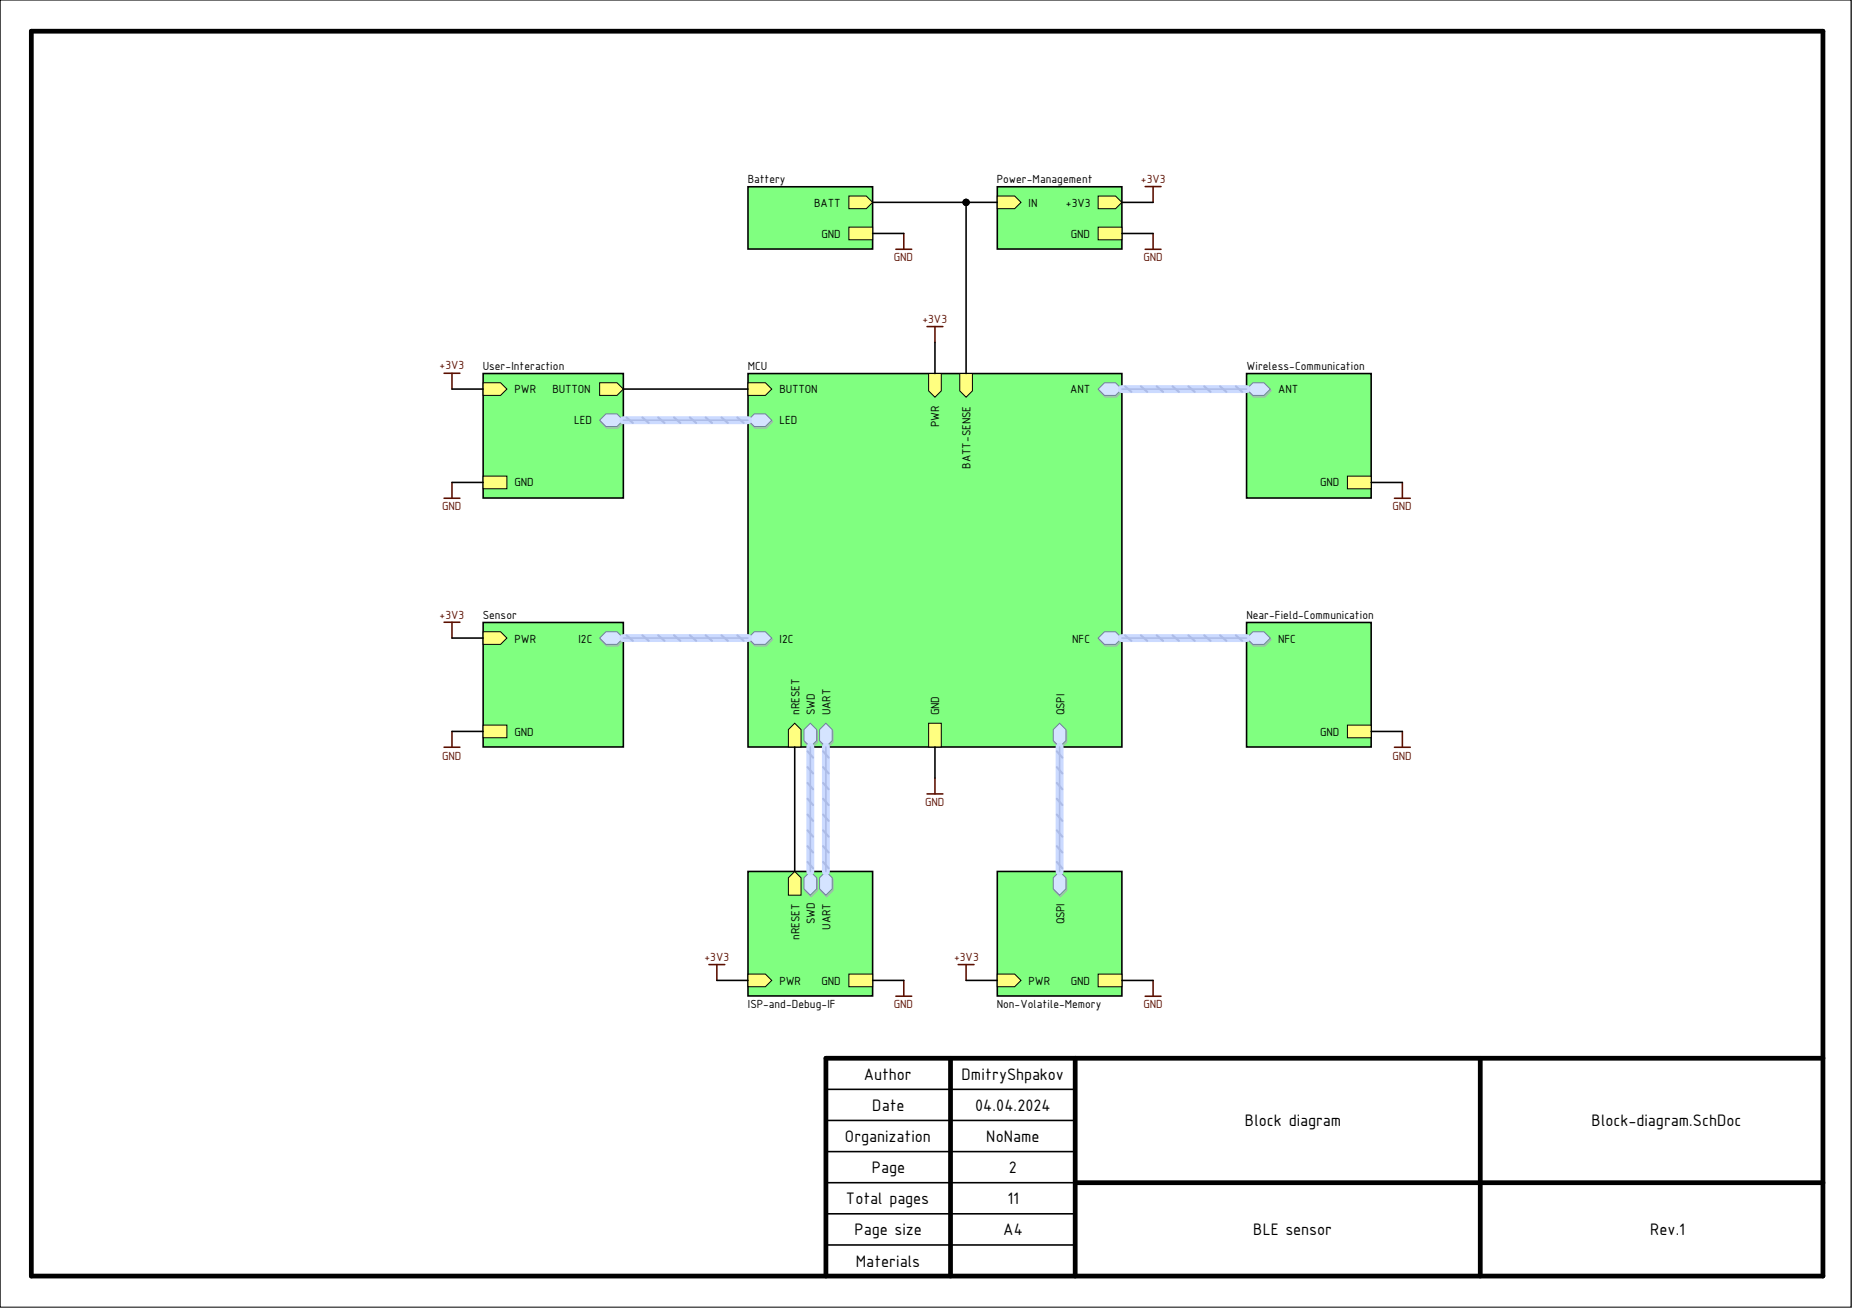
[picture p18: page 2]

ISP-and-Debug-IF

Author | DmitryShpakov | Block diagram | Block-diagram.SchDoc

Date | 04.04.2024

Organization | NoName

Page | 2

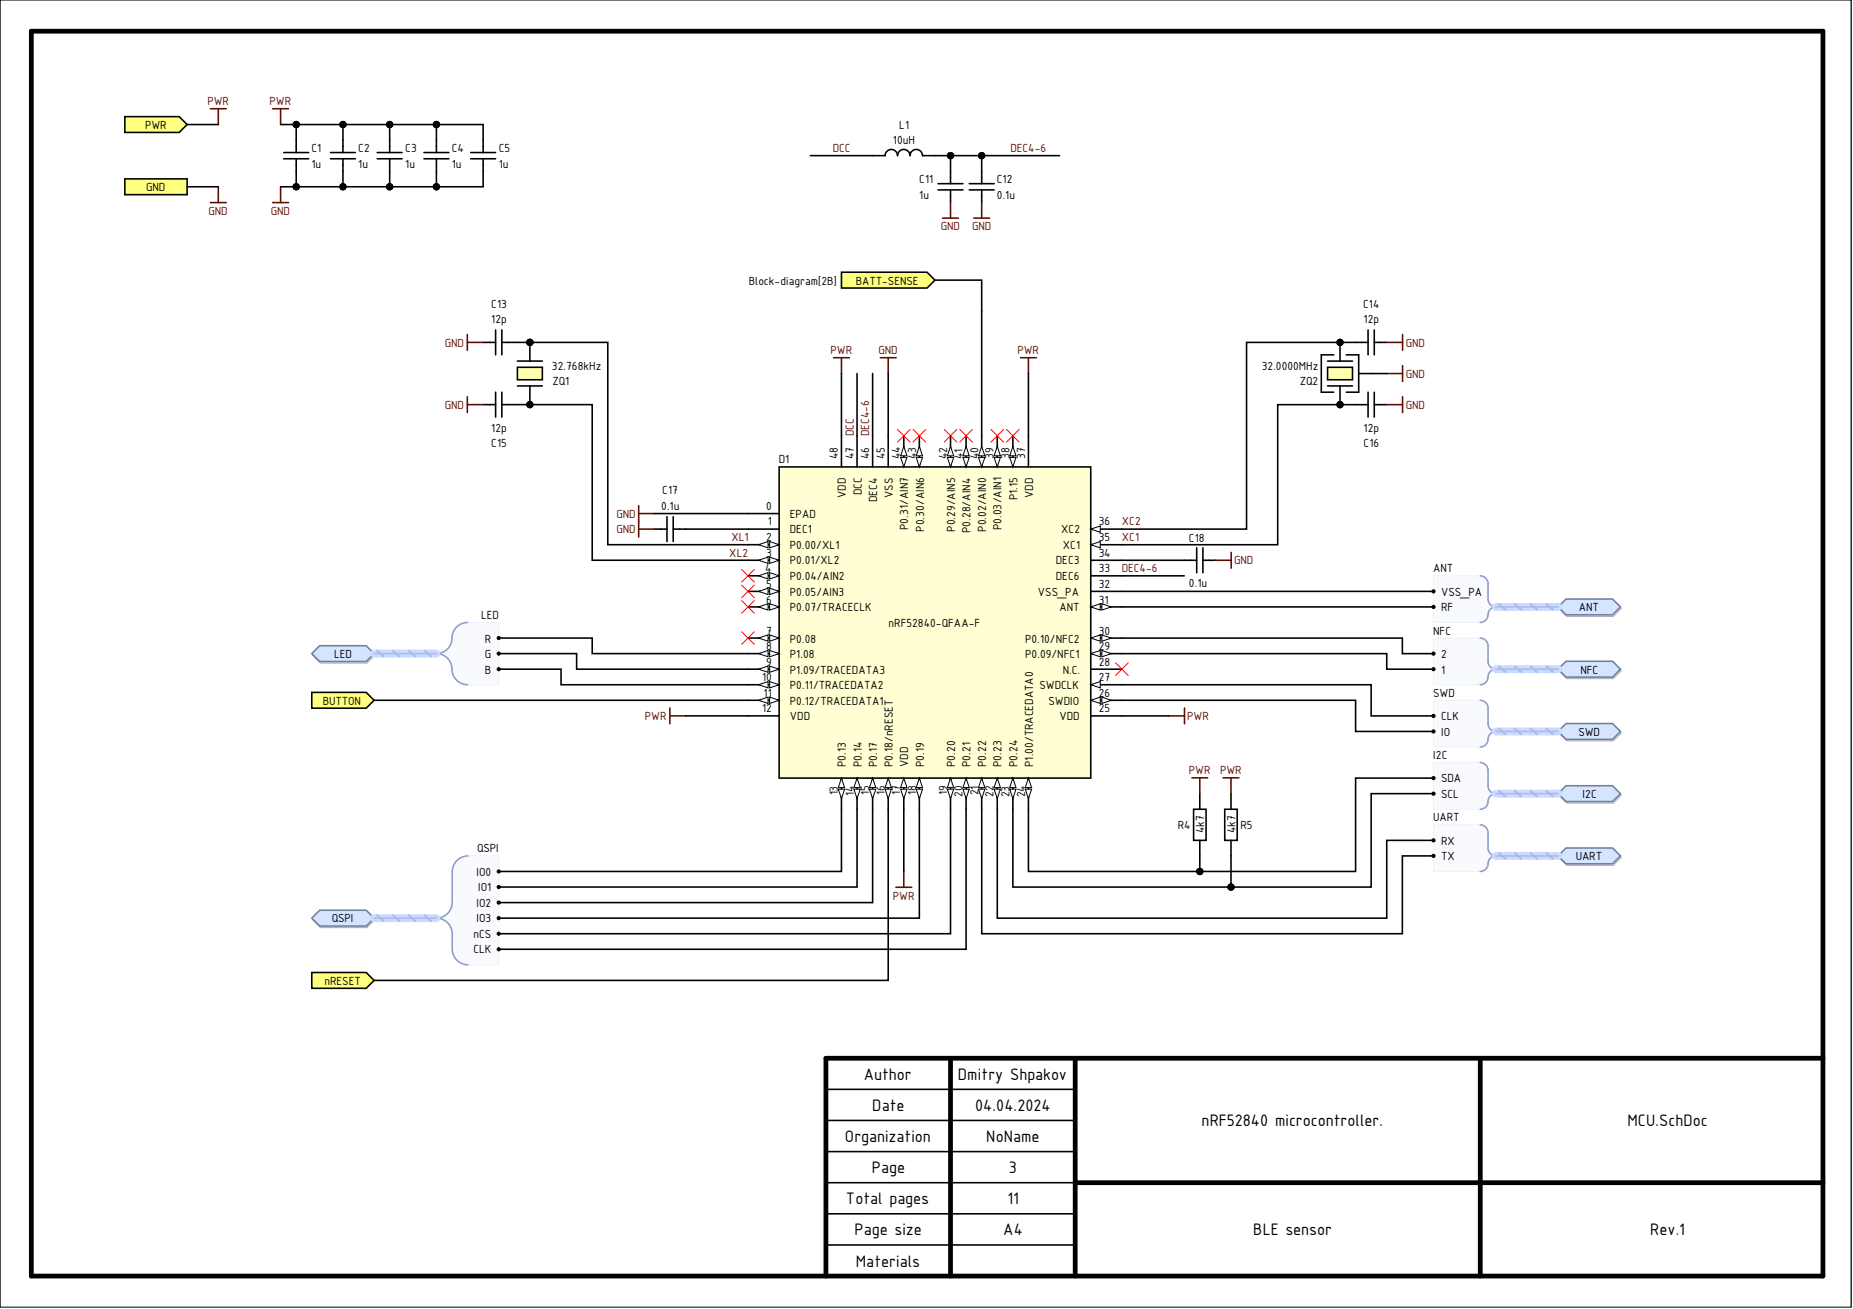
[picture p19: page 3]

XL1 | | DEC1 1 P0.00/XL1 2

P0.11/TRACEDATA2 10

Author | Dmitry Shpakov | nRF52840 microcontroller. | MCU.SchDoc

Date | 04.04.2024

Organization | NoName

Page | 3

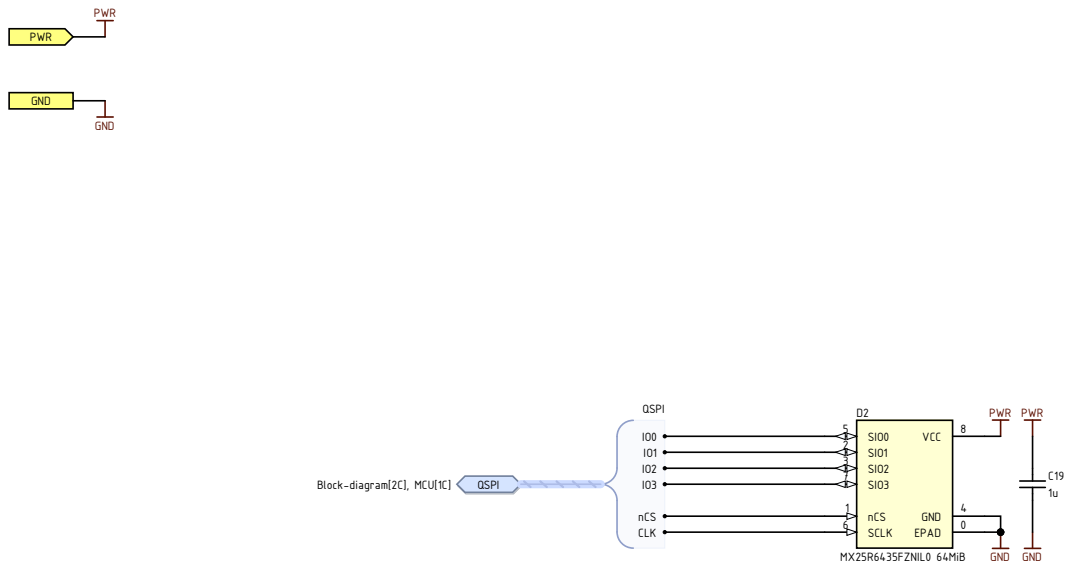
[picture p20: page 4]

Author | Dmitry Shpakov | Non volatile 64MiB NOR flash memory. | Non-Volatile-Memory.SchDoc

Date | 04.04.2024

Organization | NoName

Page | 4

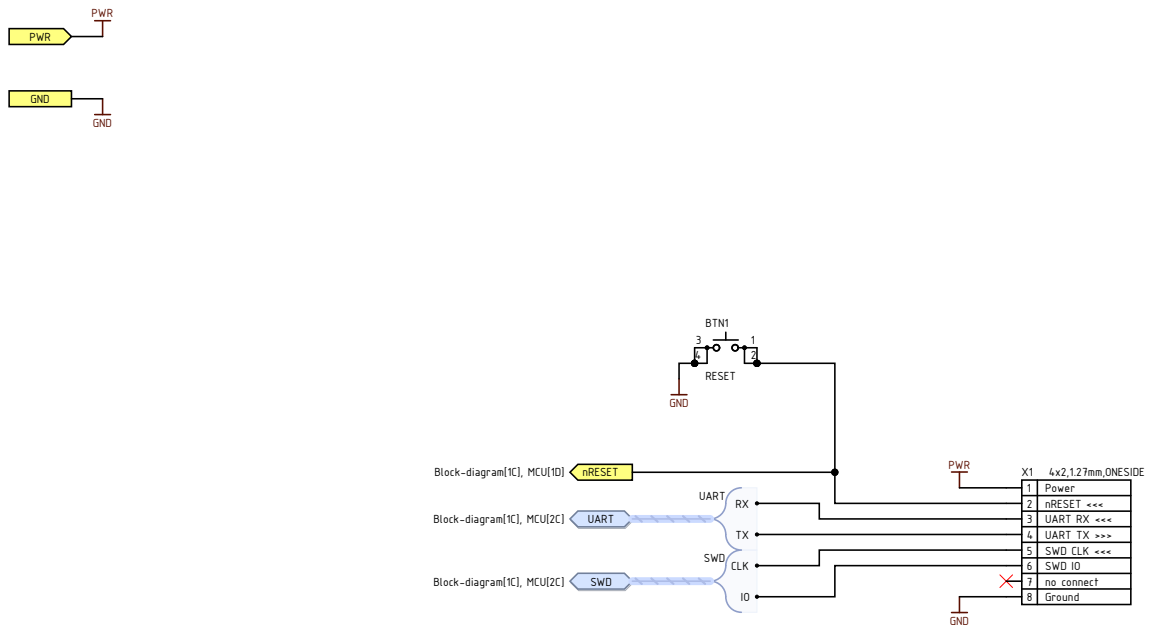
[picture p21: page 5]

1 | Power
2 | nRESET <<<
3 | UART RX <<<
4 | UART TX >>>
5 | SWD CLK <<<
6 | SWD IO
7 | no connect
8 | Ground

Author | Dmitry Shpakov | Programming and debug interface. | ISP-and-Debug-IF.SchDoc

Date | 04.04.2024

Organization | NoName

Page | 5

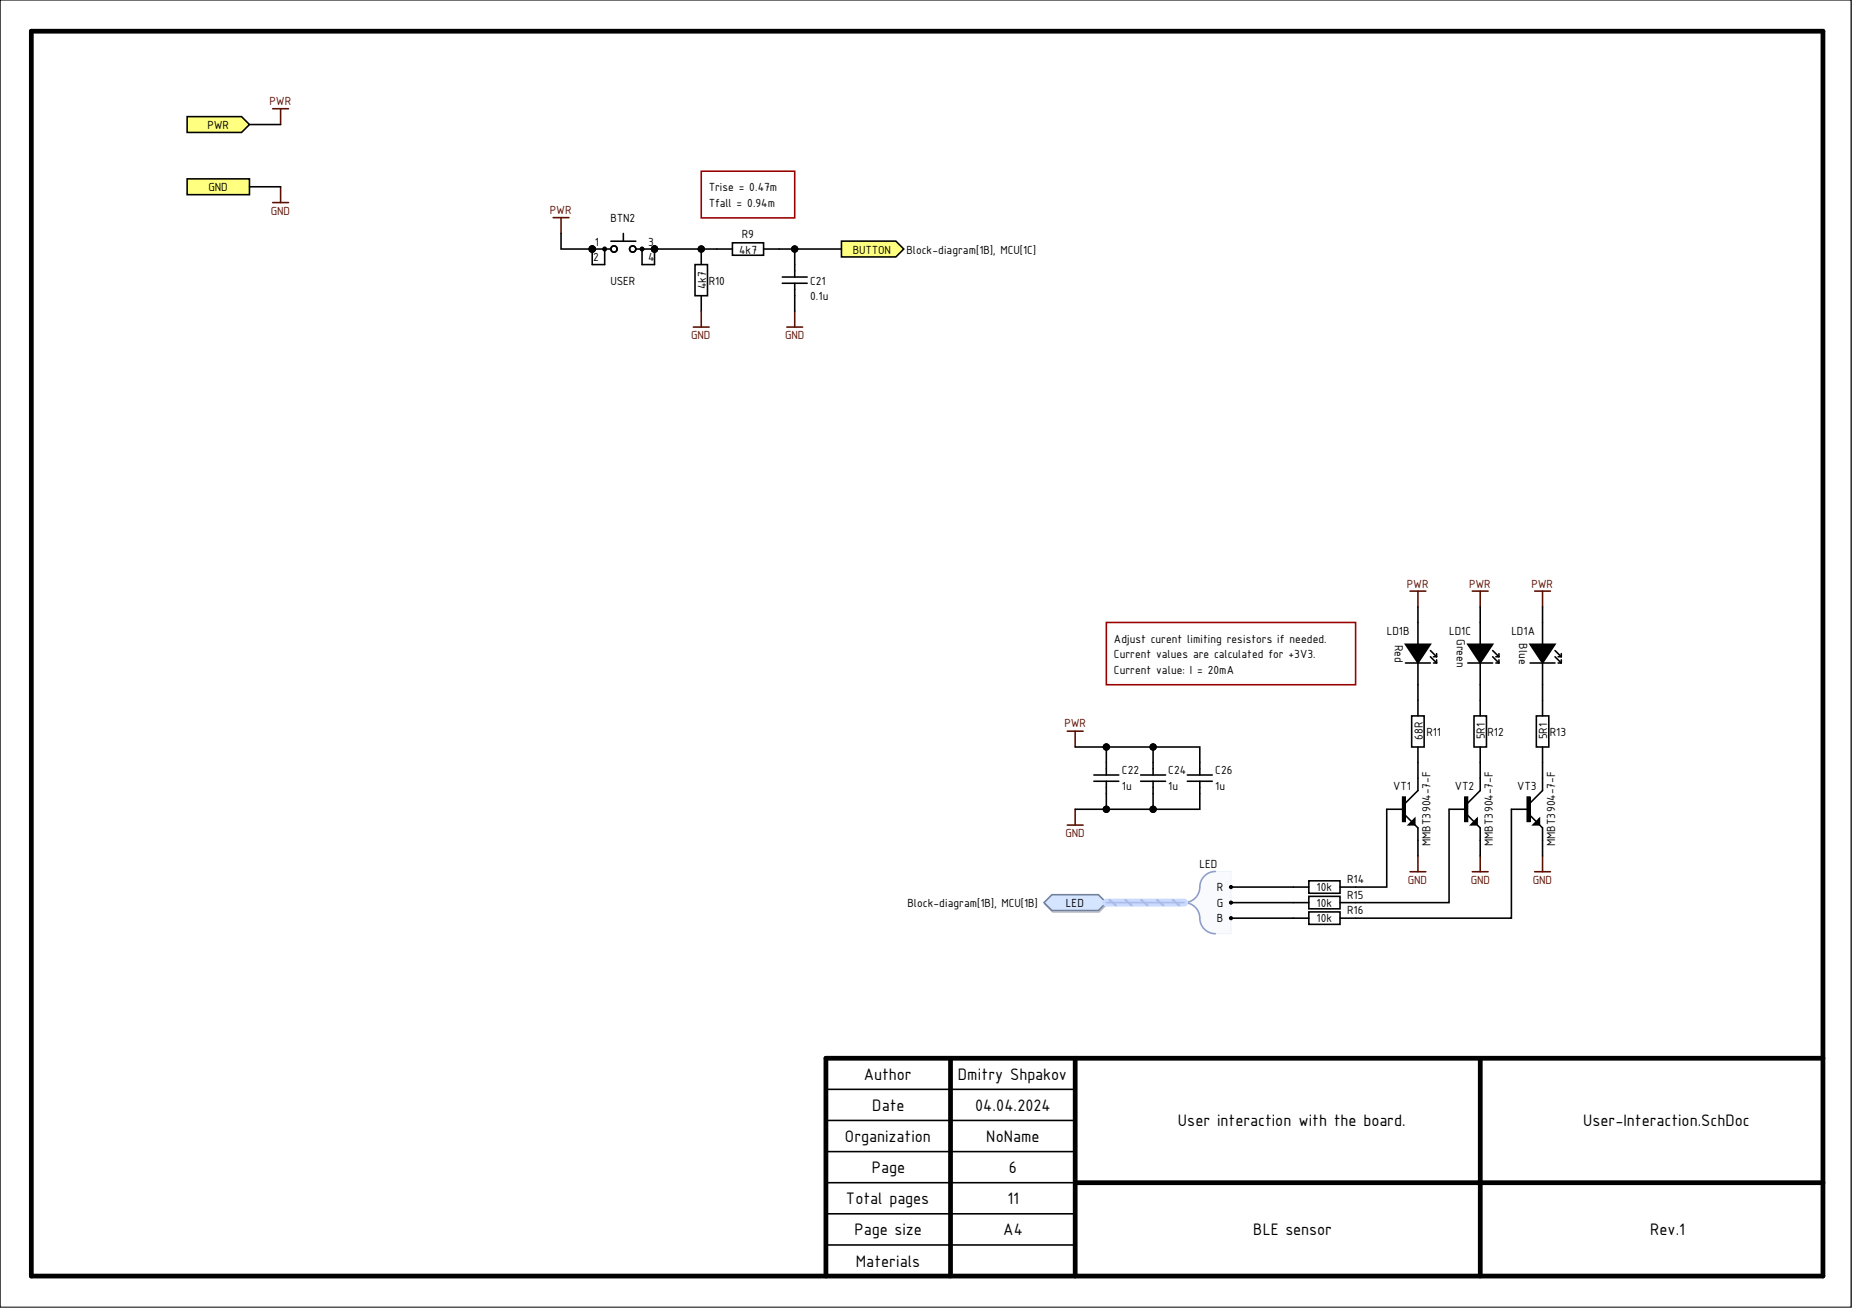
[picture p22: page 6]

Adjust curent limiting resistors if needed.
Current values are calculated for +3V3.
Current value: I = 20mA

Author | Dmitry Shpakov | User interaction with the board. | User-Interaction.SchDoc

Date | 04.04.2024

Organization | NoName

Page | 6

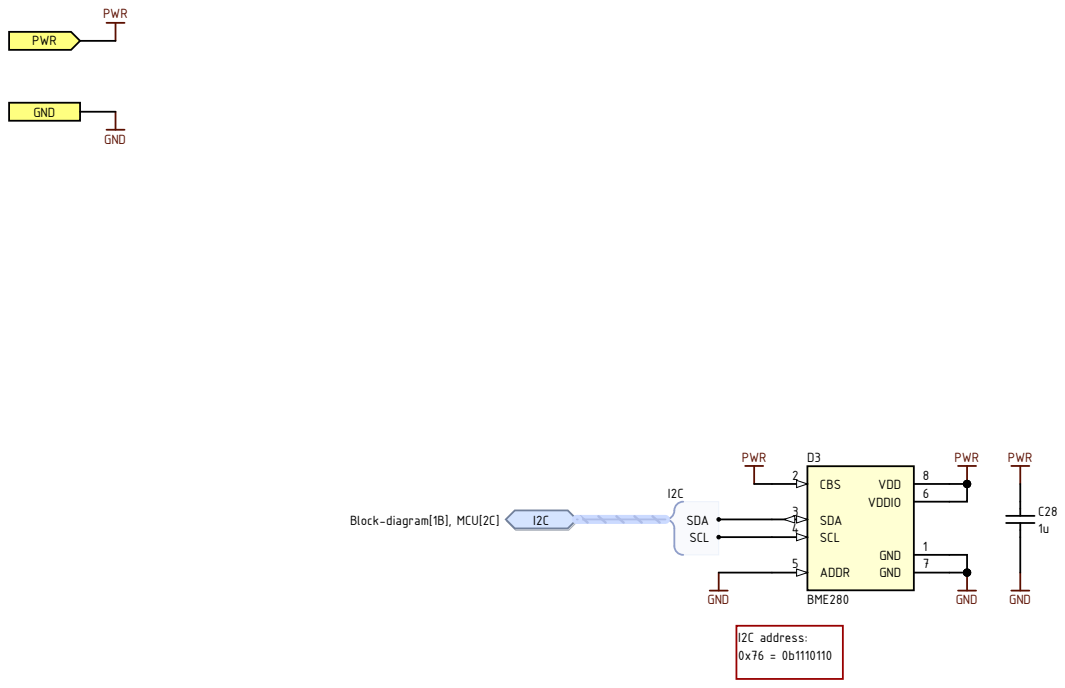
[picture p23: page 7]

Author | Dmitry Shpakov | Temperature, Pressure and Humidity sensor. | Sensor.SchDoc

Date | 04.04.2024

Organization | NoName

Page | 7

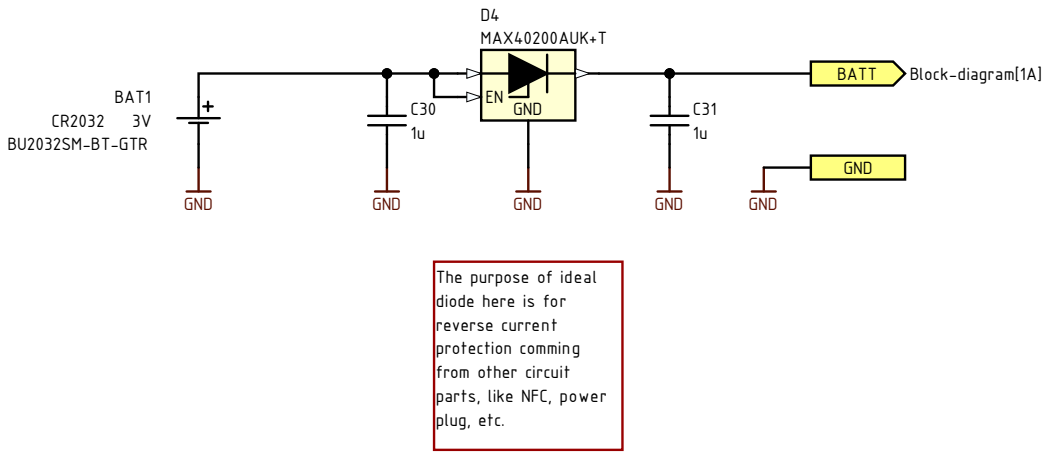
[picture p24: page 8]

Materials Page size | A4 Dmitry Shpakov NoName 8

Author Date | BLE sensor Batteries. | Battery. SchDoc

Organization Page Total pages

Rev.

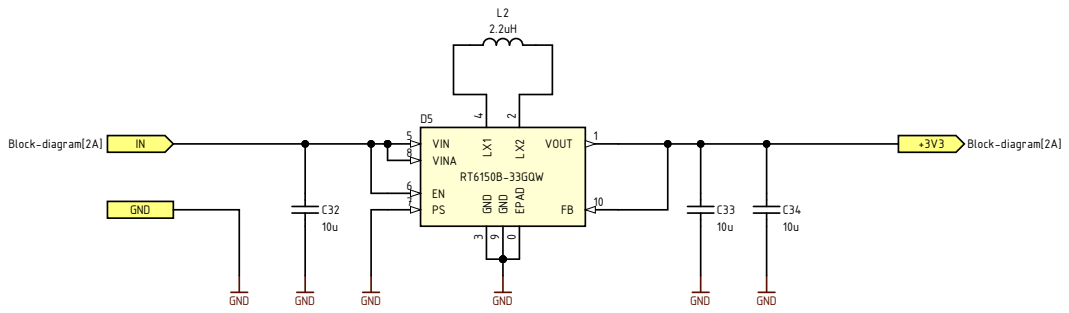
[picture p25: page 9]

Materials Page size | A4 Dmitry Shpakov NoName 9

Author Date | Buck Boost converter. | Power-Management. SchDoc

Organization Page Total pages

Rev.

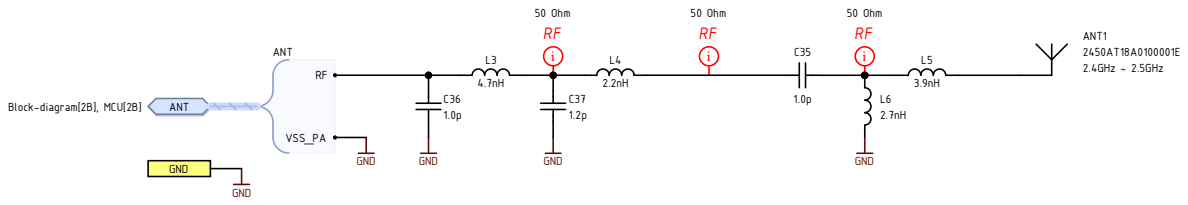
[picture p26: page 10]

Materials Page size | A4 Dmitry Shpakov NoName

Author Date | 2. 4 G Hz antenna and matching circuitry. | Wireless-Communication. SchDoc

Organization Page Total pages | 10

Rev.

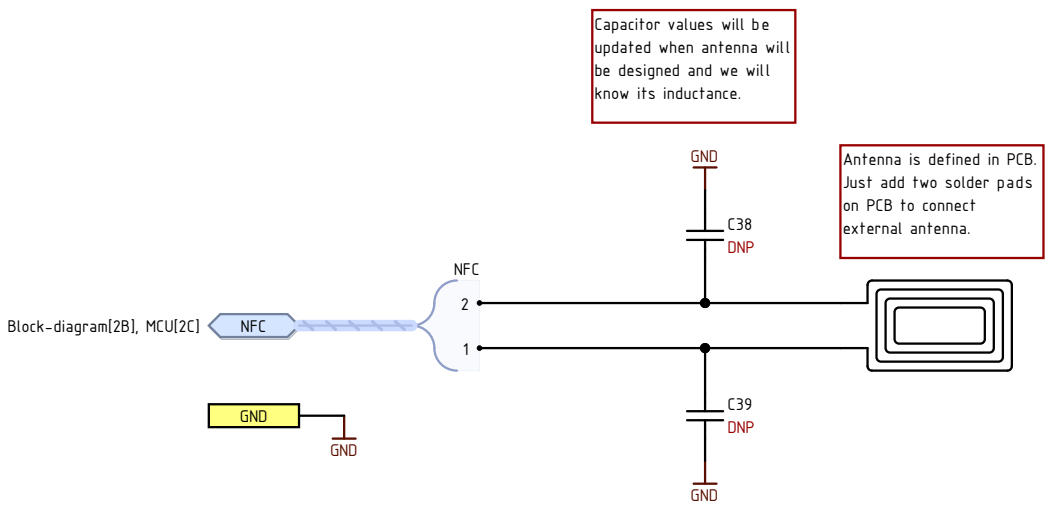
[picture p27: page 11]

Capac
updated when antenna will
be designed and we will
know

tor values will be

Materials Page size | A4 Dmitry Shpakov NoName

Author Date | NFC antenna and its matching circuitry. | Near-Field-Communication. SchDoc

Organization Page Total pages | 11

Rev.

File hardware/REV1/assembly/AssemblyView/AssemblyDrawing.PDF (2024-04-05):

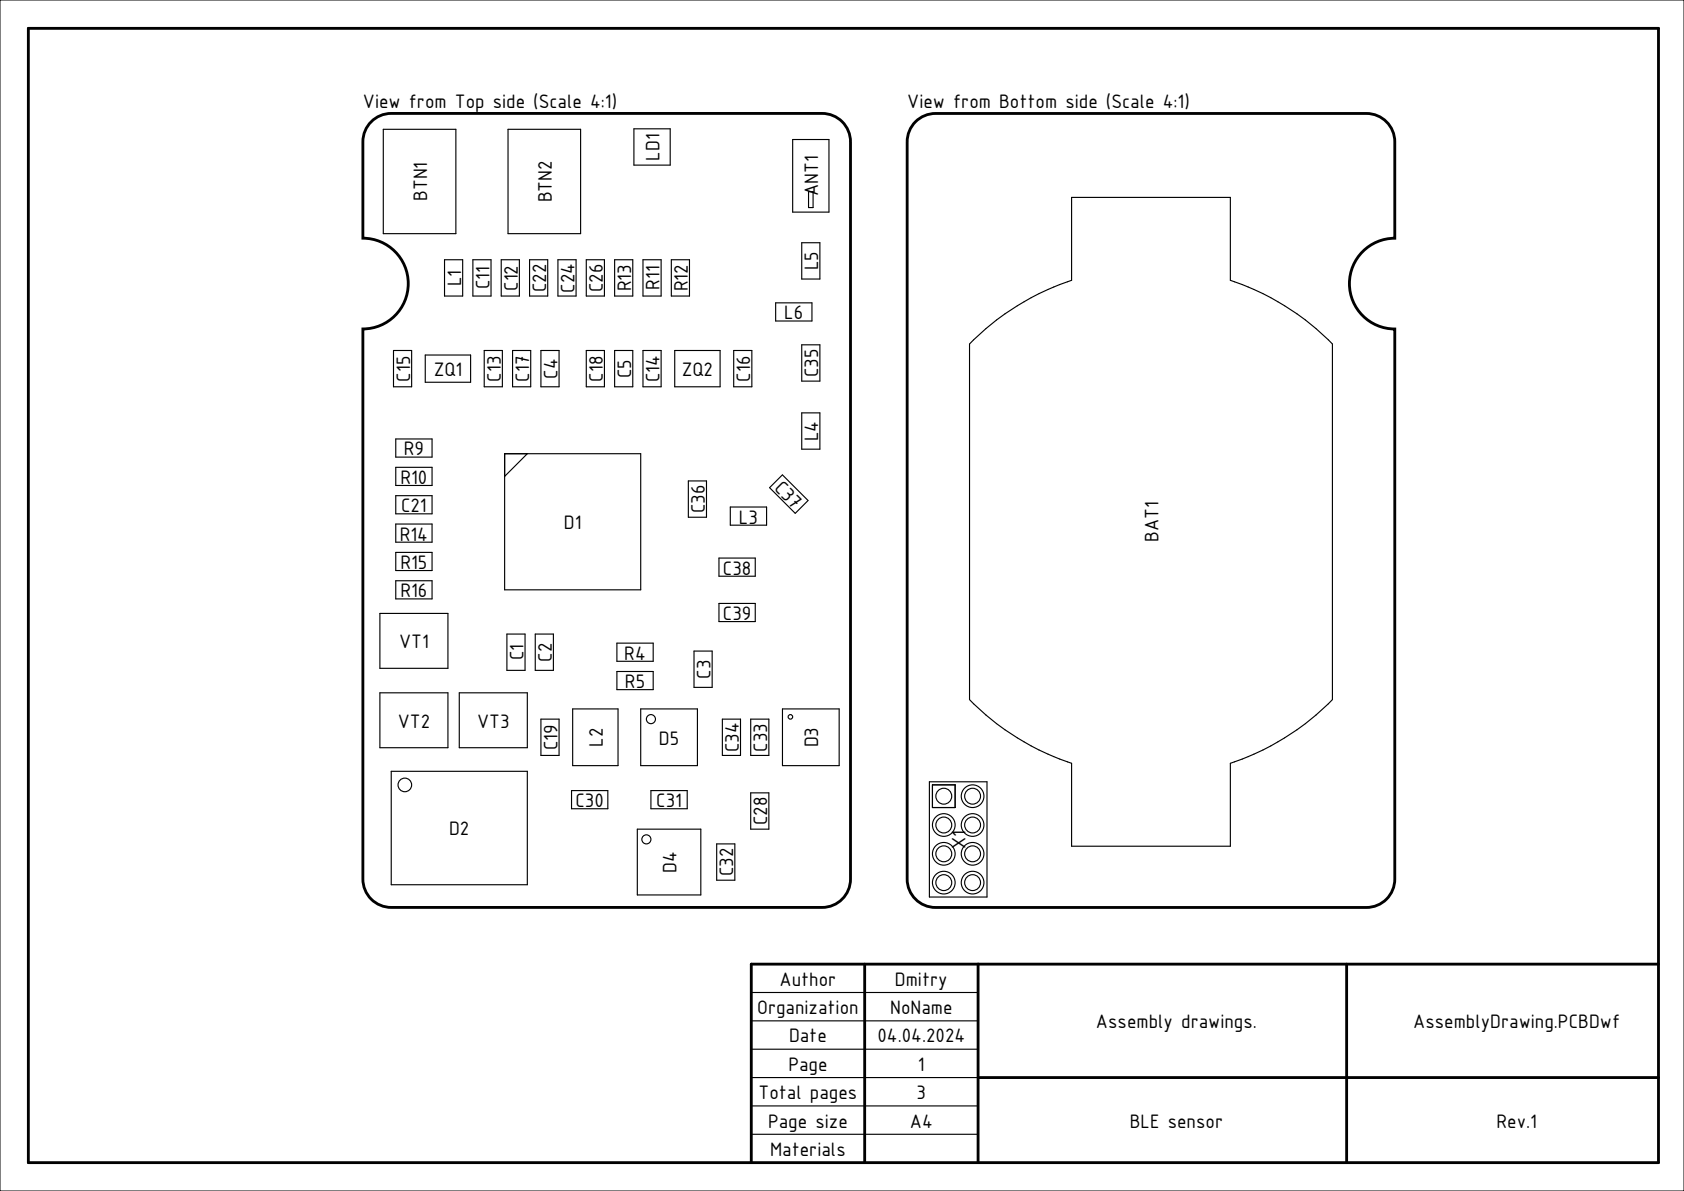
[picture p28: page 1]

View from Top side (Scale 4:1)

View from Bottom side (Scale 4:1)

Author | Dmitry | Assembly drawings. | AssemblyDrawing.PCBDwf
Organization | NoName
Date | 04.04.2024
Page | 1
Total pages | 3 | BLE sensor | Rev.1
Page size | A4
Materials


View from Front side (Scale 2:1)

View from Bottom side (Scale 2:1)

View from Back side (Scale 2:1)


Author | Dmitry | Assembly drawings. | AssemblyDrawing.PCBDwf
Organization | NoName
Date | 04.04.2024
Page | 3
Total pages | 3

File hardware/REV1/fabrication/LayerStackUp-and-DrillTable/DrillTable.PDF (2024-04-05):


Drill Drawing View (Scale 3:1) (Top view)

Symbol | Count | Hole Size | Plated | Hole Type | Drill Layer Pair | Via / Pad
180 | 0.350mm | Plated | Round | Top Layer - Bottom Layer | Via
180 Total

Author | Dmitry | Drill table. | DrillTable.PCBDwf
Organization | NoName
Date | 04.04.2024
Page | 1
Total pages | 1 | BLE sensor | Rev.1
Page size | A4
Materials

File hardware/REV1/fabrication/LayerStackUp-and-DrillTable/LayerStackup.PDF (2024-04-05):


NOTES: UNLESS OTHERWISE SPECIFIED.

1. FABRICATE PER IPC-6012A CLASS 2.
2. FOR BOARD THICKNESS AND IMPEDANCE DETAILS REFER STACKUP DOCUMENT.
3. SURFACE FINISH: IMMERSION GOLD (ENIG)
4. SOLDERMASK ON BOTH SIDES OF THE BOARD SHALL BE LPI, COLOR GREEN.
5. SILK SCREEN LEGEND TO BE APPLIED PER LAYER STACKUP USING WHITE NON-CONDUCTIVE EPOXY INK.
6. THIS PRINTED CIRCUIT BOARD IS DESIGNED WITH A MINIMUM CONDUCTOR WIDTH AND SPACING OF 0.127MM & 0.127MM.
7. ALL VIAS ARE TENTED ON BOTH SIDES UNLESS SOLDERMASK OPENED IN GERBER.
8. ALL VIAS ON PAD SHOULD BE FILLED WITH NON CONDUCTIVE EPOXY.
9. SOLDER MASK OPENING IS KEPT SAME SIZE AS PAD (1:1) FOR ALL COMPONENTS
10. MANUFACTURER'S IDENTIFICATION, DATECODE LETTER SHALL BE SILKSCREENED ON SOLDER SIDE OF THE BOARD.
11. TRACE WIDTH SHOULD BE ACCURATELY ETCHED. MAX TOLERANCE +/- 1 MIL
12. ALL DIMENSIONS ARE IN MILLIMETERS UNLESS OTHERWISE SPECIFIED.
13. PCB MATERIAL REQUIREMENTS:
A. Tg 135 C OR EQUIVALENT.
14. LAYER TO LAYER REGISTRATION SHALL BE WITHIN +/-2 MIL

Author | Dmitry | Stackup | LayerStackup.PCBDwf
Organization | NoName
Date | 04.04.2024
Page | 1
Total pages | 1 | BLE sensor | Rev.1
Page size | A4
Materials

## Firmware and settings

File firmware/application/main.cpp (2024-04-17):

/* -*-c++-*-
 * @file: main.cpp
 * @author: Dmitry Shpakov
 * @date: 2024/04/17
 * @licence: LGPL3 (see text at the end of a file)
 * @description: main source file
 */

#include <application.hpp>

static Application application;

int main(int argc, char **argv) {
  application.run();
  return 0;
}

/*

Copyright © 2024 Dmitry Shpakov

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
*/

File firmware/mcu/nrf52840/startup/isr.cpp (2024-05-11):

/* -*-c++-*-
 * @file: isr.cpp
 * @author: Dmitry Shpakov
 * @date: 2024/05/11
 * @licence: LGPL3 (see text at the end of a file)
 * @description: isr vector table
 */

#include <cstdint>
#include <mcu/memory_map.hpp>

__attribute__((section(".stack"), used)) uint32_t *__stack_init = &__stacktop__;

extern "C" void __stop(void)  {
    while (true) {
        ;
    }
}

void RESET_Handler(void)        __attribute__((weak, alias("__stop")));
void NMI_Handler(void)          __attribute__((weak, alias("__stop")));
void HARDFAULT_Handler(void)    __attribute__((weak, alias("__stop")));
void MEMMANAGE_Handler(void)    __attribute__((weak, alias("__stop")));
void BUSFAULT_Handler(void)     __attribute__((weak, alias("__stop")));
void USAGEFAULT_Handler(void)   __attribute__((weak, alias("__stop")));
void SVCALL_Handler(void)       __attribute__((weak, alias("__stop")));
void PENDSV_Handler(void)       __attribute__((weak, alias("__stop")));
void SYSTICK_Handler(void)      __attribute__((weak, alias("__stop")));

void DUMMY_Handler(void)        __attribute__((weak, alias("__stop")));

__attribute__((section(".exception_vectors"), used)) funcPtr __exceptionVectors__[] = {
    RESET_Handler,
    NMI_Handler,
    HARDFAULT_Handler,
    MEMMANAGE_Handler,
    BUSFAULT_Handler,
    USAGEFAULT_Handler,
    DUMMY_Handler,
    DUMMY_Handler,
    DUMMY_Handler,
    DUMMY_Handler,
    SVCALL_Handler,
    DUMMY_Handler,
    DUMMY_Handler,
    PENDSV_Handler,
    SYSTICK_Handler
};

void POWERCLOCK_Handler(void)        __attribute__ ((weak, alias("__stop")));
void RADIO_Handler(void)             __attribute__ ((weak, alias("__stop")));
void UART0_Handler(void)             __attribute__ ((weak, alias("__stop")));
void SPI0TWI0_Handler(void)          __attribute__ ((weak, alias("__stop")));
void SPI1TWI1_Handler(void)          __attribute__ ((weak, alias("__stop")));
void NFCTAG_Handler(void)            __attribute__ ((weak, alias("__stop")));
void GPIOTE_Handler(void)            __attribute__ ((weak, alias("__stop")));
void SAADC_Handler(void)             __attribute__ ((weak, alias("__stop")));
void TIMER0_Handler(void)            __attribute__ ((weak, alias("__stop")));
void TIMER1_Handler(void)            __attribute__ ((weak, alias("__stop")));
void TIMER2_Handler(void)            __attribute__ ((weak, alias("__stop")));
void RTC0_Handler(void)              __attribute__ ((weak, alias("__stop")));
void TEMP_Handler(void)              __attribute__ ((weak, alias("__stop")));
void RNG_Handler(void)               __attribute__ ((weak, alias("__stop")));
void ECB_Handler(void)               __attribute__ ((weak, alias("__stop")));
void AARCCM_Handler(void)            __attribute__ ((weak, alias("__stop")));
void WDT_Handler(void)               __attribute__ ((weak, alias("__stop")));
void RTC1_Handler(void)              __attribute__ ((weak, alias("__stop")));
void QDEC_Handler(void)              __attribute__ ((weak, alias("__stop")));
void COMPLPCOMP_Handler(void)        __attribute__ ((weak, alias("__stop")));
void EGU0SWI0_Handler(void)          __attribute__ ((weak, alias("__stop")));
void EGU1SWI1_Handler(void)          __attribute__ ((weak, alias("__stop")));
void EGU2SWI2_Handler(void)          __attribute__ ((weak, alias("__stop")));
void EGU3SWI3_Handler(void)          __attribute__ ((weak, alias("__stop")));
void EGU4SWI4_Handler(void)          __attribute__ ((weak, alias("__stop")));
void EGU5SWI5_Handler(void)          __attribute__ ((weak, alias("__stop")));
void TIMER3_Handler(void)            __attribute__ ((weak, alias("__stop")));
void TIMER4_Handler(void)            __attribute__ ((weak, alias("__stop")));
void PWM0_Handler(void)              __attribute__ ((weak, alias("__stop")));
void PDM_Handler(void)               __attribute__ ((weak, alias("__stop")));
void ACLNVMC_Handler(void)           __attribute__ ((weak, alias("__stop")));
void PPI_Handler(void)               __attribute__ ((weak, alias("__stop")));
void MVU_Handler(void)               __attribute__ ((weak, alias("__stop")));
void PWM1_Handler(void)              __attribute__ ((weak, alias("__stop")));
void PWM2_Handler(void)              __attribute__ ((weak, alias("__stop")));
void SPI2_Handler(void)              __attribute__ ((weak, alias("__stop")));
void RTC2_Handler(void)              __attribute__ ((weak, alias("__stop")));
void I2C_Handler(void)               __attribute__ ((weak, alias("__stop")));
void FPU_Handler(void)               __attribute__ ((weak, alias("__stop")));
void USBD_Handler(void)              __attribute__ ((weak, alias("__stop")));
void UART1_Handler(void)             __attribute__ ((weak, alias("__stop")));
void QSPI_Handler(void)              __attribute__ ((weak, alias("__stop")));
void CCHOSTRGFCRYPTO_Handler(void)   __attribute__ ((weak, alias("__stop")));
void PWM3_Handler(void)              __attribute__ ((weak, alias("__stop")));
void SPI3_Handler(void)              __attribute__ ((weak, alias("__stop")));

__attribute__((section(".isr_vectors"), used)) funcPtr __isrVectors__[] = {
    POWERCLOCK_Handler,
    RADIO_Handler,
    UART0_Handler,
    SPI0TWI0_Handler,
    SPI1TWI1_Handler,
    NFCTAG_Handler,
    GPIOTE_Handler,
    SAADC_Handler,
    TIMER0_Handler,
    TIMER1_Handler,
    TIMER2_Handler,
    RTC0_Handler,
    TEMP_Handler,
    RNG_Handler,
    ECB_Handler,
    AARCCM_Handler,
    WDT_Handler,
    RTC1_Handler,
    QDEC_Handler,
    COMPLPCOMP_Handler,
    EGU0SWI0_Handler,
    EGU1SWI1_Handler,
    EGU2SWI2_Handler,
    EGU3SWI3_Handler,
    EGU4SWI4_Handler,
    EGU5SWI5_Handler,
    TIMER3_Handler,
    TIMER4_Handler,
    PWM0_Handler,
    PDM_Handler,
    ACLNVMC_Handler,
    PPI_Handler,
    MVU_Handler,
    PWM1_Handler,
    PWM2_Handler,
    SPI2_Handler,
    RTC2_Handler,
    I2C_Handler,
    FPU_Handler,
    USBD_Handler,
    UART1_Handler,
    QSPI_Handler,
    CCHOSTRGFCRYPTO_Handler,
    DUMMY_Handler,
    DUMMY_Handler,
    PWM3_Handler,
    DUMMY_Handler,
    SPI3_Handler
};

/*

Copyright © 2024 Dmitry Shpakov

This library is free software; you can redistribute it and/or modify
it under the terms of the GNU Lesser General Public License as published
by the Free Software Foundation; either version 3 of the License, or
(at your option) any later version.

This library is distributed in the hope that it will be useful,
but WITHOUT ANY WARRANTY; without even the implied warranty of
MERCHANTABILITY or FITNESS FOR A PARTICULAR PURPOSE. See the
GNU Lesser General Public License for more details.

You should have received a copy of the GNU Lesser General Public License
along with this library; if not, see <http://www.gnu.org/licenses/>.

*/

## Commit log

2024-04-05 added hardware files for manufacture, assembly and documentation
    [Bill of Materials-PCB.xlsx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]
2024-04-05 +) added missing teardrops on nets and vias
    [PCB_Board_Shape.gbr, PCB_Copper_Signal_1.gbr, PCB_Copper_Signal_2.gbr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]
2024-04-05 +) added some images og board and layers
2024-04-05 +) added link to actual schematics
2024-04-05 +) added board view from both sides for case with components on PCB and without them
2024-04-06 moved to REV1 directory
    [Bill of Materials-PCB.xlsx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]
